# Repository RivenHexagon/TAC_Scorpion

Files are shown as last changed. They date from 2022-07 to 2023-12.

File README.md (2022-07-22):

# TAC_Scorpion
## Mixing Console S1100 Channel Modification

This modification **splits** the TAC Scorpion **S1100** channel **modules** into three **groups** and **modifies** them accordingly:

*   **Group 1**: AML-16-007 ***Mic Input*** Modification<br>
    <http://www.audiomaintenance.com/acatalog/AML-16-007_extended_info.html>
*   **Group 2**: AML-16-004 ***Line Input*** Modification<br>
    <http://www.audiomaintenance.com/acatalog/AML-16-004_extended_info.html>
*   **Group 3**: SK25 ***Descrete Op-Amp*** (DOA) Modification<br>
    <https://www.soundskulptor.com/en/proddetail.php?prod=SK25>

### New Circuit Diagrams
For each modification the **circuit diagram** of the **S1100** module (PBC GL270D) is **redrawn**, reflecting the changes made.

### New Connector Cards
Further more, all **connector cards** are **redesigned**, providing a single layer **PCB layout** for **DIY** manuafcturing. It has slight improvements and allowes for the replacement of old **corroded** connectors with **new** gold plated components.

### This Repo
This repository provides all the **design resources** created for this project. The majority of the modifications are **based** on the reverse engineering of the above linked **Audio Maintenance Limited** products and the **Sound Sculptor** kit.

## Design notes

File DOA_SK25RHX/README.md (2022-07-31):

## Soundskulptor SK 25
<https://www.soundskulptor.com/en/proddetail.php?prod=SK25>
The SK25 Descrete OpAmp module is redesigned with our own layout for DIY process.

### AMEK/TAC Scorpion 2520 Differential Mod

<https://www.pcbway.com/project/share/AMEK_TAC_Scorpion_2520_Differential_Mod___.html>

This is an image
This is an image
This is an image

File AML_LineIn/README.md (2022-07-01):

# AML_TAC_LineIn
Schematic for PCB AML-07-046 (Rev 3)

AML-16-004 - TAC Scorpion "Langley" Line Input Modification Kit (S1000 & S1100)

Langley Designs modification kit for TAC Scorpion (S1000 or S1100) input modules.

Replaces Mic input with Line Level Only input for DAW applications.

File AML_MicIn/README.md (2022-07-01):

# AML_TAC_MicIn
Schematic for PCB AML-07-048 (Rev 4)

AML-16-007 - TAC Scorpion "Langley" Mic Input Upgrade Kit (S1000 & S1100)

Langley Designs mic input upgrade modification kit for TAC Scorpion S1000 & S1100 input modules.

* C01 - 2n2 K100
* C02 - 47u 63 V
* C03 - 47u 63 V
* C04 - 3m3 10 V
* C12 - 3m3 10 V
* C05 - 47u 25 V
* C06 - 47u 25 V
* C07 - 47u 25 V
* C08 - 47u 25 V
* C14 - 47u 25 V
* C20 - 100u 10V

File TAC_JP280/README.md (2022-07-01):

# Total Audio Concepts (TAC) Scorpion Mixing Console Overhaul
## PCB JP280

Redesign of Monitor Connector Card (PCB JP280) in order to populate it with gold
plated Audio Jacks and Molex connectors. The original PCB exceeds the dimensions
of an Eurocard (100 mm x 160 mm) substrate. Luckily it's possible to split it up
into two independet parts, so the layouts can be placed on a copper-plated blank
and etched in a DIY process (see mirrored image of original PCB).

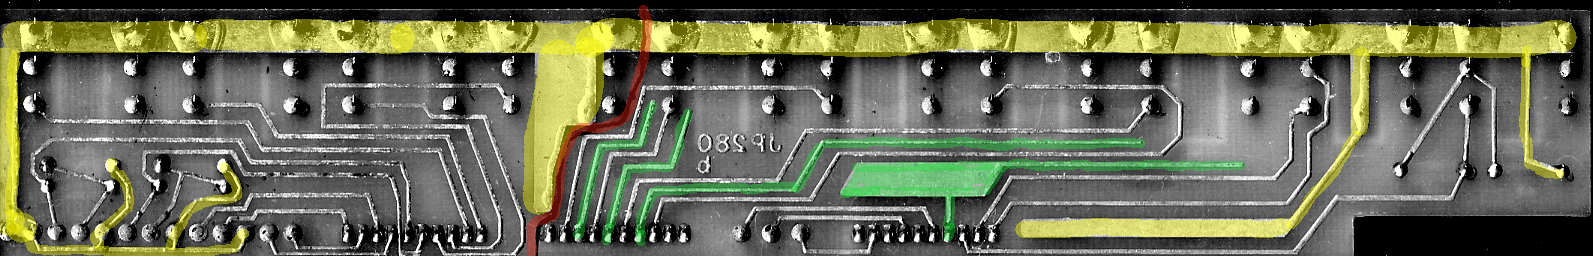
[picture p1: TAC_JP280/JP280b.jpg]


## Made With

I named the new versions JP280C1 & JP280C2 and made them with KiCad 5.1.7. using
a git submodule that handles any special footprints:

https://github.com/RivenHexagon/TAC_KiCad_lib.git

## Further Modifications

The XLR/audio jacks SK1 - SK4 are mounted to the back panel and were then solder
wired to the PCB. The solder connections have now been replaced with 3-pin Molex
connectors.

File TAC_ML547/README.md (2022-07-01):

# Total Audio Concepts (TAC) Scorpion Mixing Console Overhaul
## PCB ML547

Redesign of the Input/Insert Connector Card (PCB ML547) in order to populate it
with gold plated Audio Jacks. The original dimensions are 100 mm x 40 mm. Only
two of them where installed in my TAC scorpion, hence two layouts fit half a
copper plated Eurocard (100 mm x 80 mm) substrate for DIY etching.

## Made With

I named the new version ML547D and made them with KiCad 5.1.7. using a git
submodule that handles any special footprints:

https://github.com/RivenHexagon/TAC_KiCad_lib.git

## Further Modifications

One copper trace of the old layout follows a very narrow path between two pins
of the left and right insert jacks (highlighted in the mirrored PCB image). The
new layout provides this connection with a trace on the top layer. For my single
layer DIY substrate I've used a simple wire.

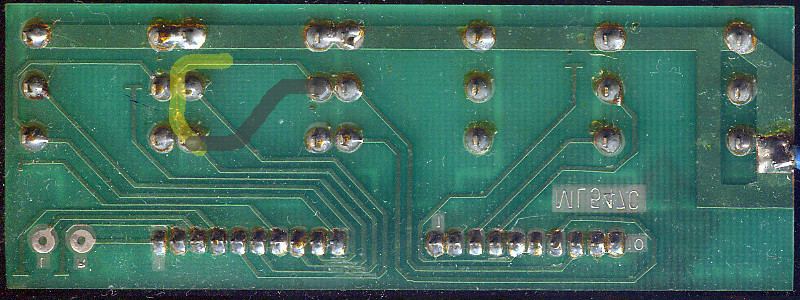
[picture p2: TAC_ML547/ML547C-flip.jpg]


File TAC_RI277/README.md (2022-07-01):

# Total Audio Concepts (TAC) Scorpion Mixing Console Overhaul
## PCB RI277

Redesign of the Input Connector Card (PCB RI277) in order to populate it
with gold plated Audio Jacks. I made 6 of them fit a copper plated Eurocard
(100 mm x 80 mm) substrate for DIY etching.

## Made With

I named the new version RI277D and made them with KiCad 5.1.7. using a git
submodule that handles any special footprints:

https://github.com/RivenHexagon/TAC_KiCad_lib.git

## Further Modifications

The XLR Bus Out connectors were panel mounted and solder wired to the PCB as
well as the Tape Return wiring harness. I've provided two 3-pin Molex connectors
instead.

Mirrored image of the original PCB:

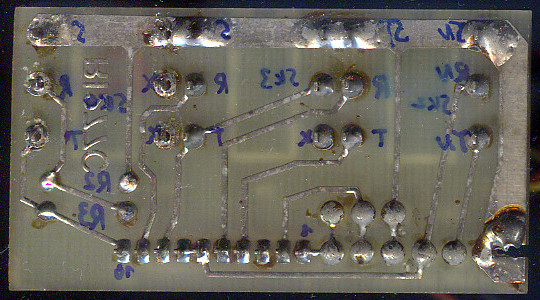
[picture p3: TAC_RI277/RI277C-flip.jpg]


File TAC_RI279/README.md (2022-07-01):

# Total Audio Concepts (TAC) Scorpion Mixing Console Overhaul
## PCB RI279

Redesign of the Bus Connector Card (PCB RI279) in order to populate it
with gold plated Audio Jacks. I made 8 of them fit a copper plated Eurocard
(100 mm x 80 mm) substrate for DIY etching.

## Made With

I named the new version RI279C and made them with KiCad 5.1.7. using a git
submodule that handles any special footprints:

https://github.com/RivenHexagon/TAC_KiCad_lib.git

## Further Modifications

The XLR Bus Out connectors were panel mounted and solder wired to the PCB as
well as the Tape Return wiring harness. I've provided two 3-pin Molex connectors
and a 2-pole pin header (GND and signal) for the wire ging out to the vu-meter.

Mirrored image of the original PCB:

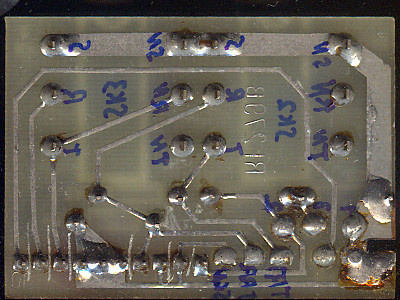
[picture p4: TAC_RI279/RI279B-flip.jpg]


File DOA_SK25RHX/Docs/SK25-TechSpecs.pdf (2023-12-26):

Sound Skulptor - SK 25

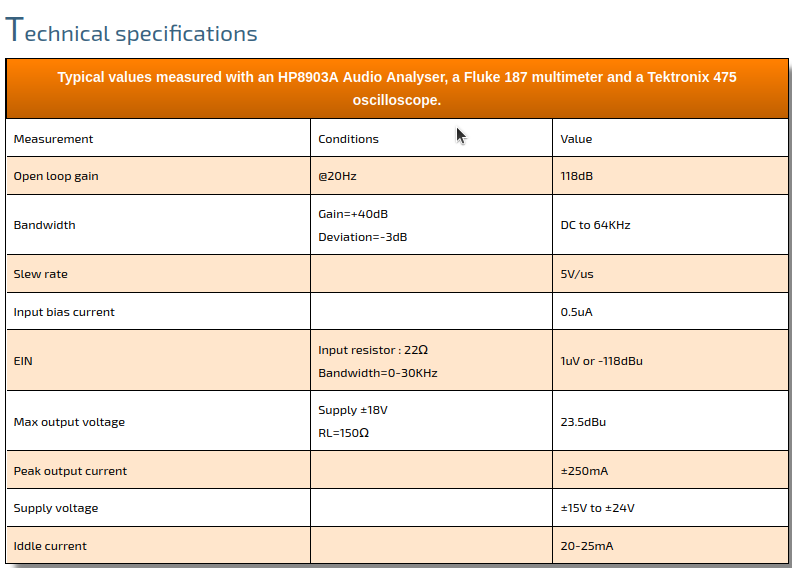
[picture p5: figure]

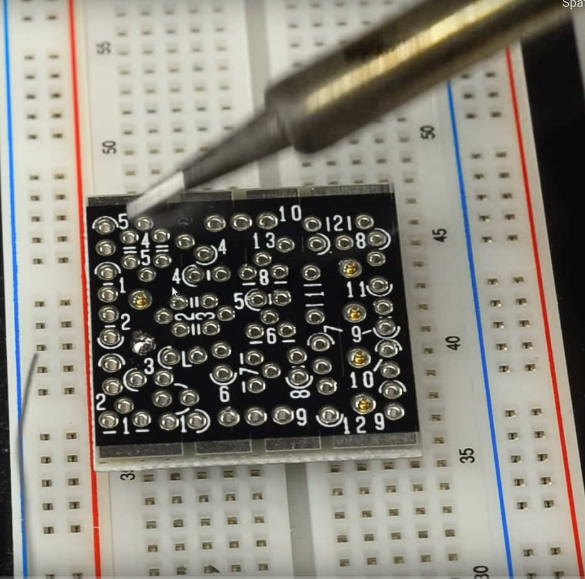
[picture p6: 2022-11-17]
DOA_SK25RHX/Docs/dimensions.jpg

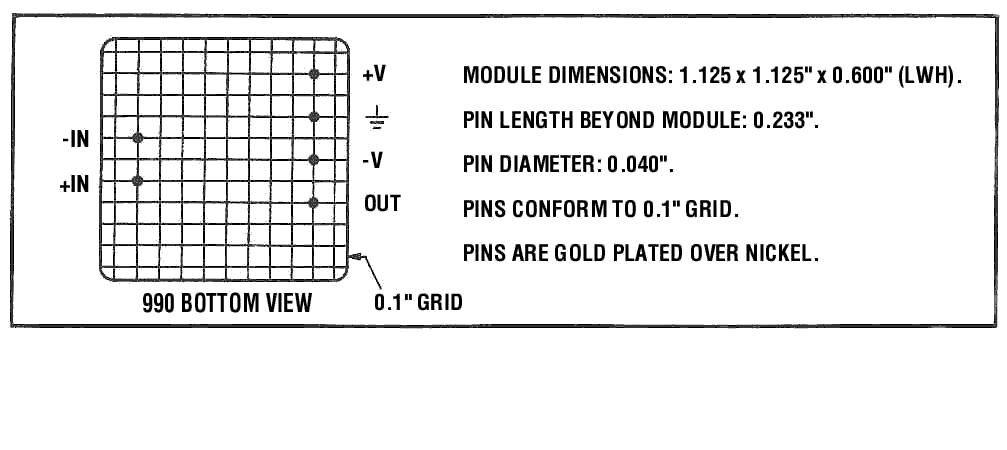
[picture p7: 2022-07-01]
DOA_SK25RHX/Docs/990-2520-footprint.jpeg

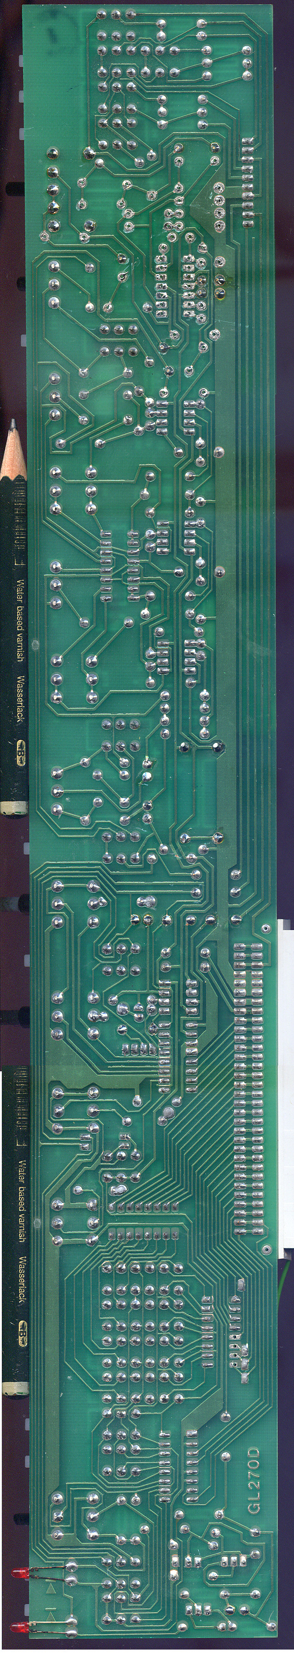
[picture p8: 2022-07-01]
TAC_GL270D/GL270-DOA2520.kicad_pro/PCB_GL270D.jpg

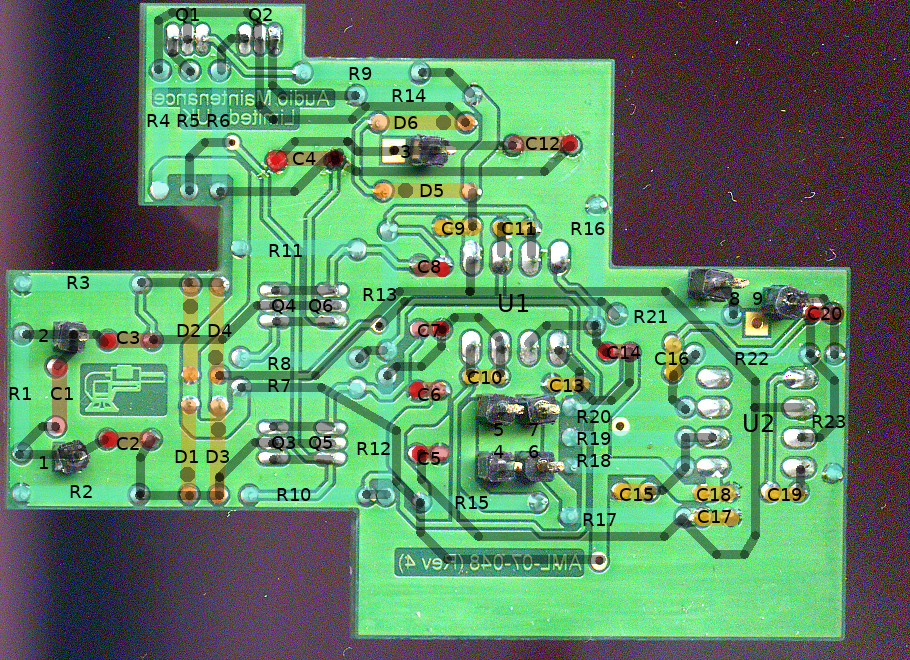
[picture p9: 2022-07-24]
AML_MicIn/AML-MicIn.jpg

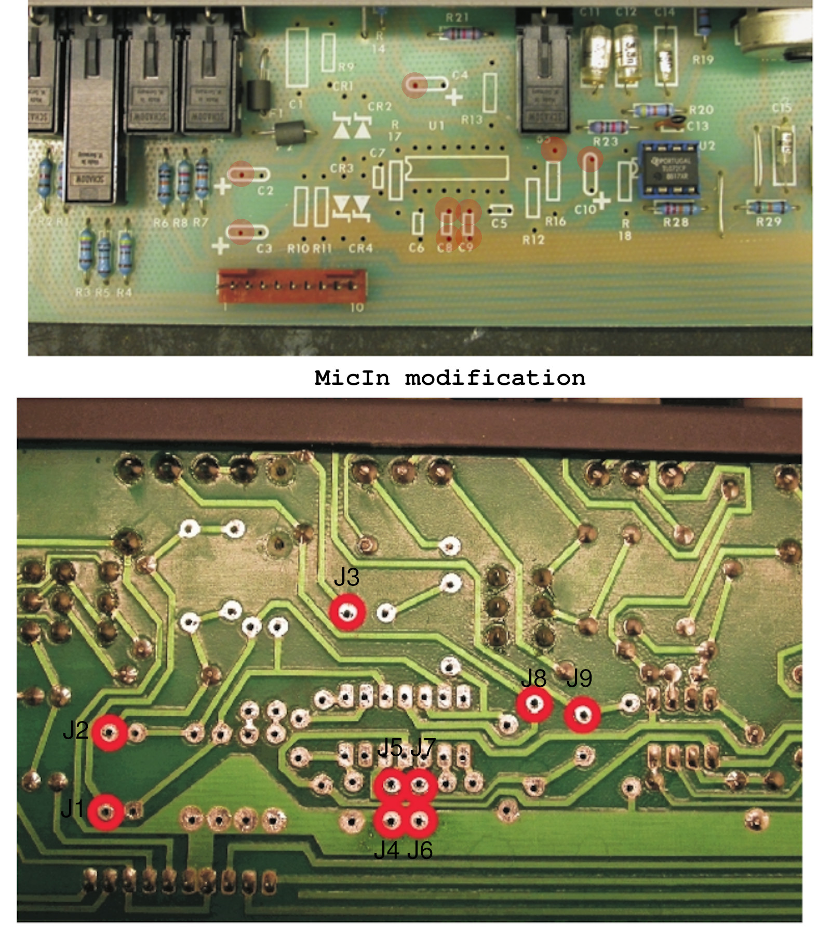
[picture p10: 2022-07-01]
AML_MicIn/MicIn-mod.jpg

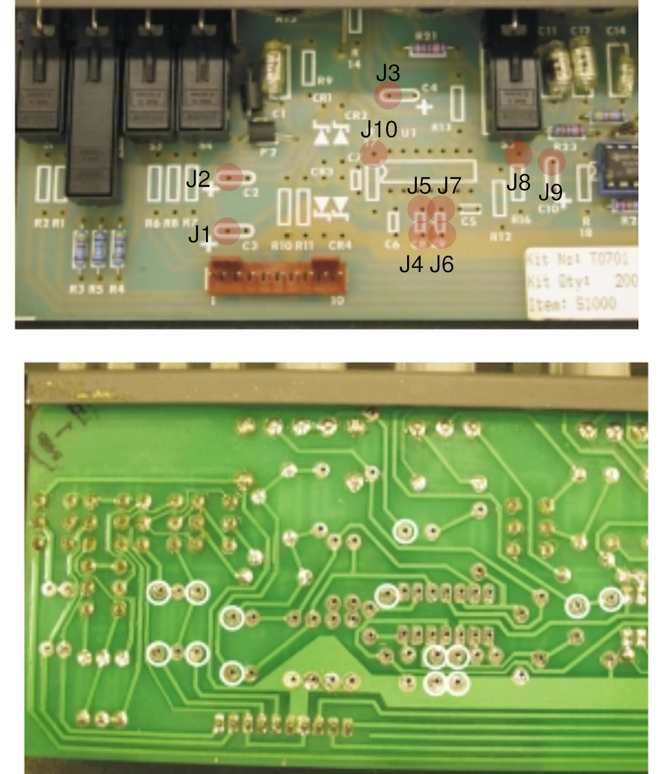
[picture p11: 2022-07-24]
AML_LineIn/LineIn-mod.jpg

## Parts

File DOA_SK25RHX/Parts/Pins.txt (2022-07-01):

 (6) Mill-Max #3103200210000080 @ $0.20 each
Contact Finish: 20μ" Gold Over Nickel
Flange Diameter: 0.070" (1.77mm)
Plated Thru Hole Diameter: 0.043" (1.09mm)
Pin Diameter: 0.040" (1.02mm)
Length: 0.402" (10.21mm)

https://www.digikey.de/products/de?keywords=3103-2-00-21-00-00-08-0
https://capi-gear.com/catalog/product_info.php?products_id=215

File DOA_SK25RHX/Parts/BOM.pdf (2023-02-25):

Sheet1

Reference(s) Value | LibPart
C1 | 100pF | Device:C
C2 | 220pF | Device:C
D1 | 1N914 | Device:D
D2 | 1N914 | Device:D
D3 | red | Device:LED
D4 | Z5V1 | Device:D_Zener
D5 | 1N914 | Device:D
D6 | 1N914 | Device:D
D7 | 1N914 | Device:D
D8 | 1N914 | Device:D
D9 | 1N914 | Device:D
J1 | Input- | Connector:Conn_01x01_Male
J2 | Input+ | Connector:Conn_01x01_Male
J3 | V+ | Connector:Conn_01x01_Male
J4 | Output | Connector:Conn_01x01_Male
J5 | V- | Connector:Conn_01x01_Male
J6 | GND | Connector:Conn_01x01_Male
L1 | 22µH | Device:L
Q1 | BC560C | Device:Q_PNP_CBE
Q2 | KSA992 | Device:Q_PNP_ECB
Q3 | KSA992 | Device:Q_PNP_ECB
Q4 | BC550C | Device:Q_NPN_CBE
Q5 | BC550C | Device:Q_NPN_CBE
Q6 | BC550C | Device:Q_NPN_CBE
Q7 | BC556C | Device:Q_PNP_CBE
Q8 | BC546C | Device:Q_NPN_CBE
Q9 | BD139 | Device:Q_NPN_ECBC
Q10 | BD140 | Device:Q_PNP_ECBC
R1 | 2k2 | Device:R
R2 | 100R | Device:R
R3 | 100R | Device:R
R4 | 2k2 | Device:R
R5 | 2k2 | Device:R
R6 | 22k | Device:R
R7 | 39R | Device:R
R8 | 2k2 | Device:R
R9 | 220R | Device:R
R10 | 22R | Device:R
R11 | 100R | Device:R
R12 | 5R6 | Device:R
R13 | 5R6 | Device:R

Sheet1

Footprint

Capacitor_THT:C_Disc_D5.0mm_W2.5mm_P2.50mm

Capacitor_THT:C_Disc_D5.0mm_W2.5mm_P2.50mm

Diode_THT:D_DO-35_SOD27_P2.54mm_Vertical_KathodeUp

Diode_THT:D_DO-35_SOD27_P2.54mm_Vertical_KathodeUp

LED_THT:LED_D3.0mm

Diode_THT:D_DO-35_SOD27_P2.54mm_Vertical_AnodeUp

Diode_THT:D_DO-35_SOD27_P10.16mm_Horizontal

Diode_THT:D_DO-35_SOD27_P10.16mm_Horizontal

Diode_THT:D_DO-35_SOD27_P2.54mm_Vertical_KathodeUp

Diode_THT:D_DO-35_SOD27_P2.54mm_Vertical_KathodeUp

Diode_THT:D_DO-35_SOD27_P2.54mm_Vertical_KathodeUp

Connector_Pin:Pin_D1.1mm_L8.5mm_W2.5mm_FlatFork

Connector_Pin:Pin_D1.1mm_L8.5mm_W2.5mm_FlatFork

Connector_Pin:Pin_D1.1mm_L8.5mm_W2.5mm_FlatFork

Connector_Pin:Pin_D1.1mm_L8.5mm_W2.5mm_FlatFork

Connector_Pin:Pin_D1.1mm_L8.5mm_W2.5mm_FlatFork

Connector_Pin:Pin_D1.1mm_L8.5mm_W2.5mm_FlatFork

Inductor_THT:L_Axial_L6.6mm_D2.7mm_P2.54mm_Vertical_Vishay_IM-2

TAC:TO-92

TAC:TO-92

TAC:TO-92

TAC:TO-92

TAC:TO-92

TAC:TO-92

TAC:TO-92

TAC:TO-92

TAC:to225_std

TAC:to225_std

Resistor_THT:R_Axial_DIN0207_L6.3mm_D2.5mm_P2.54mm_Vertical

Resistor_THT:R_Axial_DIN0207_L6.3mm_D2.5mm_P2.54mm_Vertical

Resistor_THT:R_Axial_DIN0207_L6.3mm_D2.5mm_P2.54mm_Vertical

Resistor_THT:R_Axial_DIN0207_L6.3mm_D2.5mm_P2.54mm_Vertical

Resistor_THT:R_Axial_DIN0207_L6.3mm_D2.5mm_P2.54mm_Vertical

Resistor_THT:R_Axial_DIN0207_L6.3mm_D2.5mm_P2.54mm_Vertical

Resistor_THT:R_Axial_DIN0207_L6.3mm_D2.5mm_P2.54mm_Vertical

Resistor_THT:R_Axial_DIN0207_L6.3mm_D2.5mm_P2.54mm_Vertical

Resistor_THT:R_Axial_DIN0207_L6.3mm_D2.5mm_P2.54mm_Vertical

Resistor_THT:R_Axial_DIN0207_L6.3mm_D2.5mm_P2.54mm_Vertical

Resistor_THT:R_Axial_DIN0207_L6.3mm_D2.5mm_P2.54mm_Vertical

Resistor_THT:R_Axial_DIN0207_L6.3mm_D2.5mm_P2.54mm_Vertical

Resistor_THT:R_Axial_DIN0207_L6.3mm_D2.5mm_P2.54mm_Vertical

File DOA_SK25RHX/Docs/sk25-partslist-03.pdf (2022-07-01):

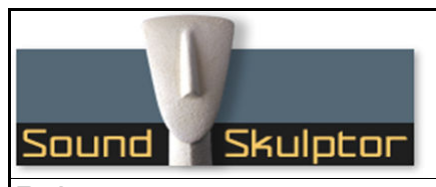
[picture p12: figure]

Reference | Value | Qty | Description | Marking
R12, R13 | 5R6 | 2 | Resistor 1%, 1/4W | GRN-BLU-BLK-SLV
R10 | 22R | 1 | Resistor 1%, 1/4W | RED-RED-BLK-GLD-BRN
R7 | 39R | 1 | Resistor 1%, 1/4W | ORG-WHT-BLK-GLD-BRN
R2, R3, R11 | 100R | 3 | Resistor 1%, 1/4W | BRN-BLK-BLK-BLK-BRN
R9 | 220R | 1 | Resistor 1%, 1/4W | RED-RED-BLK-BLK-BRN
R1, R4, R5, R8 | 2K2 | 4 | Resistor 1%, 1/4W | RED-RED-BLK-BRN-BRN
R6 | 22K | 1 | Resistor 1%, 1/4W | RED-RED-BLK-RED-BRN
L1 | 22uH | 1 | Inductor | RED-RED-BLK-SLV
C1 | 100pF | 1 | Capacitor ceramic | 101
C2 | 220pF | 1 | Capacitor ceramic | 221
D1, D2, D5, D6, D7, D8, D9 | 1N914 | 7 | Signal diode | 914 or 4148
D3 | Red | 1 | Red LED
D4 | 5.1V | 1 | Zener diode | BZX55C 5V1
Q1 | BC560C | 1 | PNP small signal transistor | BC560C
Q2, Q3 | KSA992 | 2 | PNP small signal transistor | A992
Q4, Q5, Q6 | BC550C | 3 | NPN small signal transistor | BC550C
Q7 | BC556C | 1 | PNP small signal transistor | BC556C
Q8 | BC546C | 1 | NPN small signal transistor | BC546C
Q9 | BD139 | 1 | NPN power transistor | BD139
Q10 | BD140 | 1 | PNP power transistor | BD140
| | 6 | connecting pin (golden)
PCB | | 1 | PCB
Power transistor assembly | M3x12 | 2 | Screw pan head
Power transistor assembly | M3x20 | 1 | Spacer

Last modified : 10/09/2016

### SK25 Parts list (1)

All the components in this list are included in the kit

(1) Data can be changed without notice
Page 1/1 | Copyright ©2007-today SoundSkulptor

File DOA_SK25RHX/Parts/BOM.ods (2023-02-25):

Reference(s) | Value | LibPart | Footprint
C1 | 100pF | Device:C | Capacitor_THT:C_Disc_D5.0mm_W2.5mm_P2.50mm
C2 | 220pF | Device:C | Capacitor_THT:C_Disc_D5.0mm_W2.5mm_P2.50mm
D1 | 1N914 | Device:D | Diode_THT:D_DO-35_SOD27_P2.54mm_Vertical_KathodeUp
D2 | 1N914 | Device:D | Diode_THT:D_DO-35_SOD27_P2.54mm_Vertical_KathodeUp
D3 | red | Device:LED | LED_THT:LED_D3.0mm
D4 | Z5V1 | Device:D_Zener | Diode_THT:D_DO-35_SOD27_P2.54mm_Vertical_AnodeUp
D5 | 1N914 | Device:D | Diode_THT:D_DO-35_SOD27_P10.16mm_Horizontal
D6 | 1N914 | Device:D | Diode_THT:D_DO-35_SOD27_P10.16mm_Horizontal
D7 | 1N914 | Device:D | Diode_THT:D_DO-35_SOD27_P2.54mm_Vertical_KathodeUp
D8 | 1N914 | Device:D | Diode_THT:D_DO-35_SOD27_P2.54mm_Vertical_KathodeUp
D9 | 1N914 | Device:D | Diode_THT:D_DO-35_SOD27_P2.54mm_Vertical_KathodeUp
J1 | Input- | Connector:Conn_01x01_Male | Connector_Pin:Pin_D1.1mm_L8.5mm_W2.5mm_FlatFork
J2 | Input+ | Connector:Conn_01x01_Male | Connector_Pin:Pin_D1.1mm_L8.5mm_W2.5mm_FlatFork
J3 | V+ | Connector:Conn_01x01_Male | Connector_Pin:Pin_D1.1mm_L8.5mm_W2.5mm_FlatFork
J4 | Output | Connector:Conn_01x01_Male | Connector_Pin:Pin_D1.1mm_L8.5mm_W2.5mm_FlatFork
J5 | V- | Connector:Conn_01x01_Male | Connector_Pin:Pin_D1.1mm_L8.5mm_W2.5mm_FlatFork
J6 | GND | Connector:Conn_01x01_Male | Connector_Pin:Pin_D1.1mm_L8.5mm_W2.5mm_FlatFork
L1 | 22µH | Device:L | Inductor_THT:L_Axial_L6.6mm_D2.7mm_P2.54mm_Vertical_Vishay_IM-2
Q1 | BC560C | Device:Q_PNP_CBE | TAC:TO-92
Q2 | KSA992 | Device:Q_PNP_ECB | TAC:TO-92
Q3 | KSA992 | Device:Q_PNP_ECB | TAC:TO-92
Q4 | BC550C | Device:Q_NPN_CBE | TAC:TO-92
Q5 | BC550C | Device:Q_NPN_CBE | TAC:TO-92
Q6 | BC550C | Device:Q_NPN_CBE | TAC:TO-92
Q7 | BC556C | Device:Q_PNP_CBE | TAC:TO-92
Q8 | BC546C | Device:Q_NPN_CBE | TAC:TO-92
Q9 | BD139 | Device:Q_NPN_ECBC | TAC:to225_std
Q10 | BD140 | Device:Q_PNP_ECBC | TAC:to225_std
R1 | 2k2 | Device:R | Resistor_THT:R_Axial_DIN0207_L6.3mm_D2.5mm_P2.54mm_Vertical
R2 | 100R | Device:R | Resistor_THT:R_Axial_DIN0207_L6.3mm_D2.5mm_P2.54mm_Vertical
R3 | 100R | Device:R | Resistor_THT:R_Axial_DIN0207_L6.3mm_D2.5mm_P2.54mm_Vertical
R4 | 2k2 | Device:R | Resistor_THT:R_Axial_DIN0207_L6.3mm_D2.5mm_P2.54mm_Vertical
R5 | 2k2 | Device:R | Resistor_THT:R_Axial_DIN0207_L6.3mm_D2.5mm_P2.54mm_Vertical
R6 | 22k | Device:R | Resistor_THT:R_Axial_DIN0207_L6.3mm_D2.5mm_P2.54mm_Vertical
R7 | 39R | Device:R | Resistor_THT:R_Axial_DIN0207_L6.3mm_D2.5mm_P2.54mm_Vertical
R8 | 2k2 | Device:R | Resistor_THT:R_Axial_DIN0207_L6.3mm_D2.5mm_P2.54mm_Vertical
R9 | 220R | Device:R | Resistor_THT:R_Axial_DIN0207_L6.3mm_D2.5mm_P2.54mm_Vertical
R10 | 22R | Device:R | Resistor_THT:R_Axial_DIN0207_L6.3mm_D2.5mm_P2.54mm_Vertical
R11 | 100R | Device:R | Resistor_THT:R_Axial_DIN0207_L6.3mm_D2.5mm_P2.54mm_Vertical
R12 | 5R6 | Device:R | Resistor_THT:R_Axial_DIN0207_L6.3mm_D2.5mm_P2.54mm_Vertical
R13 | 5R6 | Device:R | Resistor_THT:R_Axial_DIN0207_L6.3mm_D2.5mm_P2.54mm_Vertical

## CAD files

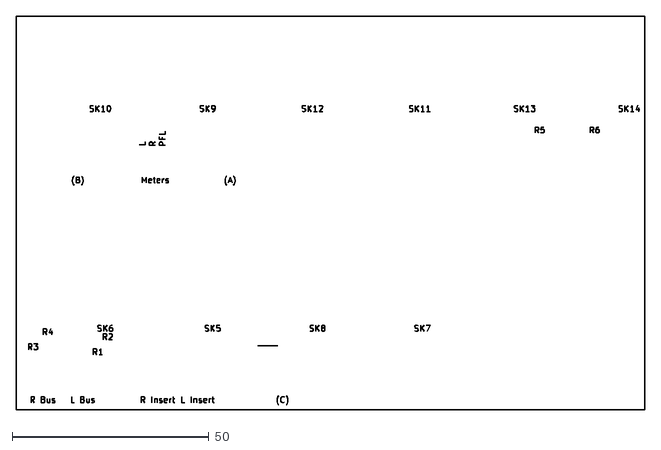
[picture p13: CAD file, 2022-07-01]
TAC_JP280/JP280C-Cmts_User.dxf
160.0 x 100.0

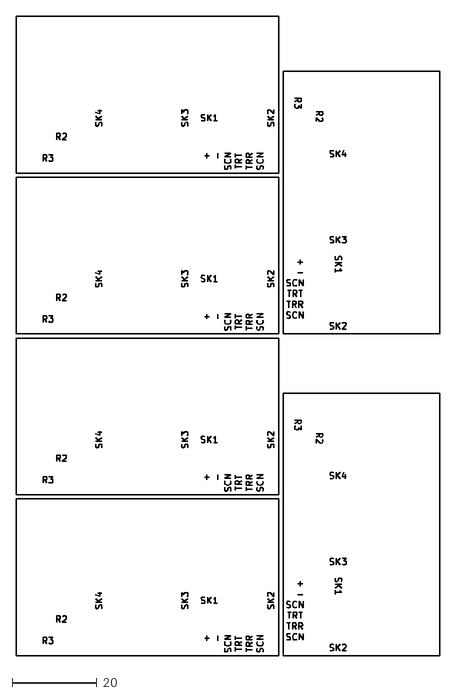
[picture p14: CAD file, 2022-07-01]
TAC_RI277/RI277D-Cmts_User.dxf
100.0 x 151.0

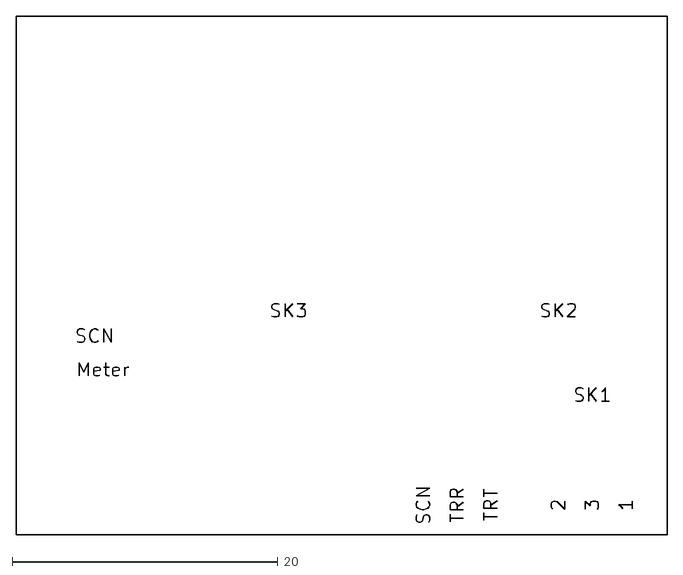
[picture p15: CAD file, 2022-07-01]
TAC_RI279/RI279C-Cmts_User.dxf
49.0 x 39.0

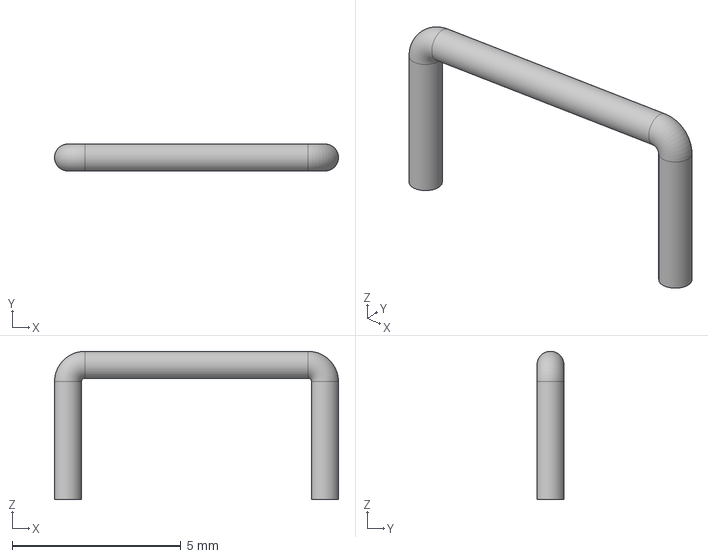
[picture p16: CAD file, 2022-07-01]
TAC_KiCad_lib/local-3dmodels/Wire_Bridge_P7.62mm.step
8.42 x 0.8 x 4.40 mm

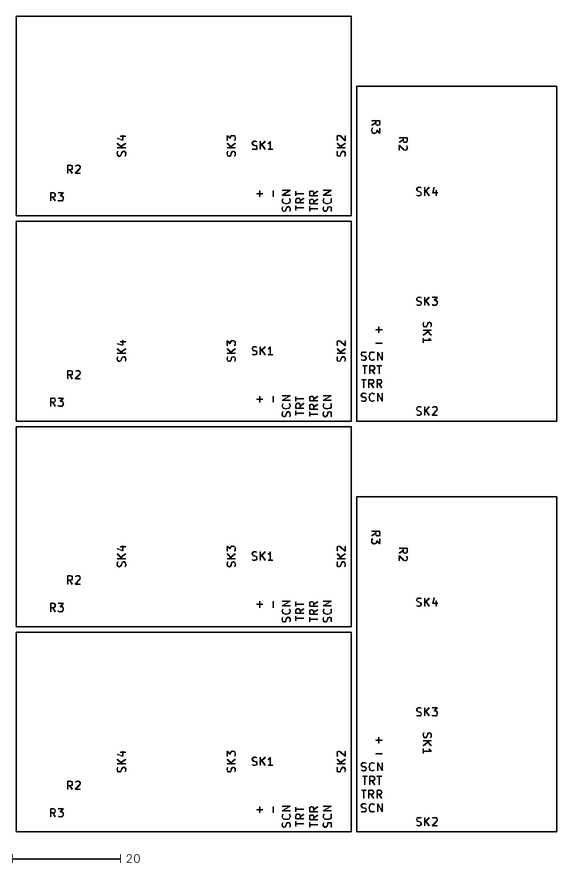
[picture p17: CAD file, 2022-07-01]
TAC_RI277/RI277D-Cmts_User-R27.dxf
100.0 x 151.0

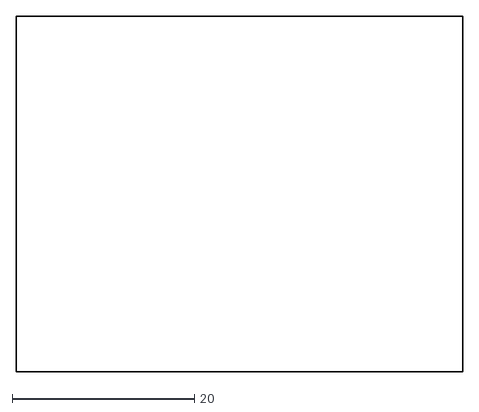
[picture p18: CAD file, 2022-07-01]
TAC_RI279/RI279C-Edge_Cuts.dxf
49.0 x 39.0

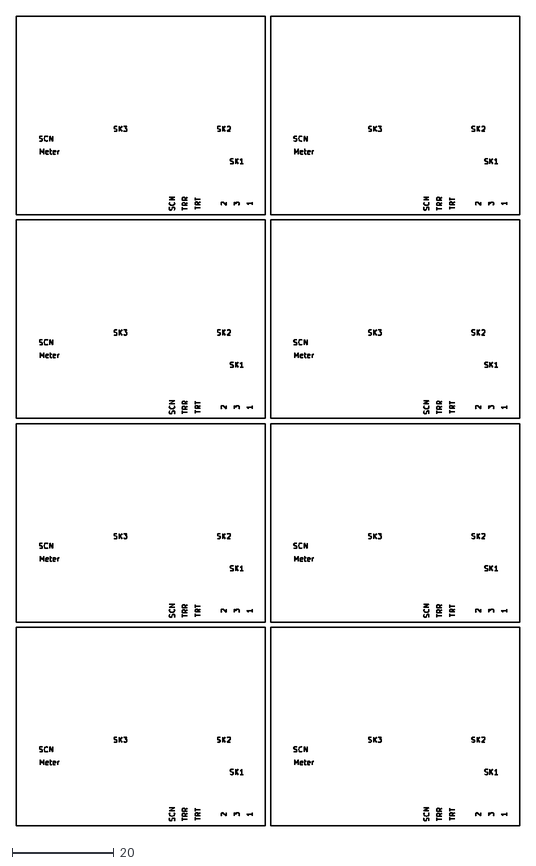
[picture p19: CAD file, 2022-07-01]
TAC_RI279/RI279C-Cmts_User-R27.dxf
99.0 x 159.0

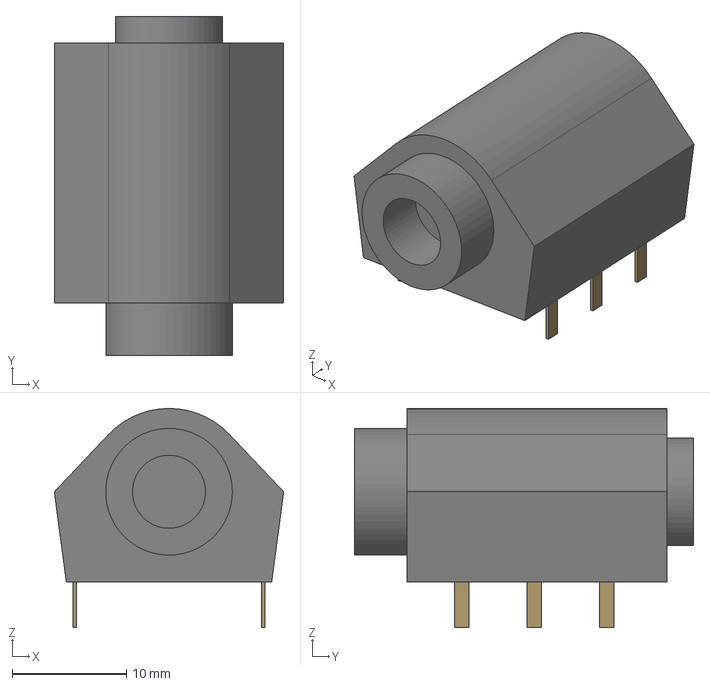
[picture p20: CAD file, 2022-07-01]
TAC_KiCad_lib/local-3dmodels/CL13345.step
20.1 x 29.7 x 19.2 mm

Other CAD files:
TAC_KiCad_lib/local-3dmodels/CL13345.FCStd
TAC_KiCad_lib/local-3dmodels/WireBridge_P7.62mm.FCStd

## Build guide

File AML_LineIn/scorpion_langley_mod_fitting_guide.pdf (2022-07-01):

# Scorpion Line Input Modification Fitting Instructions - Issue 1.1

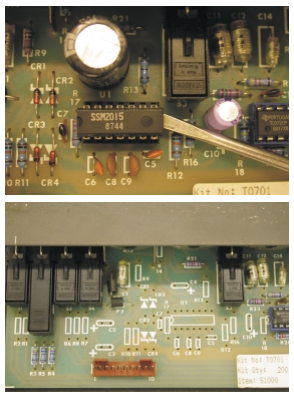
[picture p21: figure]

Carefully remove U1 (SSM2015) from its socket - Note that it is a static sensitive device and should be handled and stored appropriately.

Carefully remove the following components

Resistors; R1, R2, R6, R7, R8, R9, R10, R11, R12, R13, R14, R16, R17, R18

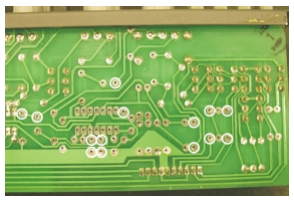
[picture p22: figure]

Capacitors; C2, C3, C4, C5, C6, C7, C8, C9, C10

Diodes; CR1, CR2, CR3, CR4

Ensure that the holes highlighted are free from solder

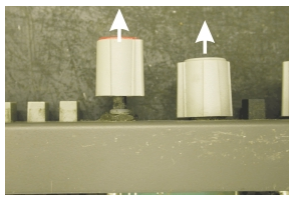
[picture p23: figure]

Carefully remove the knobs by pulling them off

{They should come off quite easily - If they do not pull off easily then remove the coloured knob cap and check to see if they are “collet” knobs with a nut inside the knob}

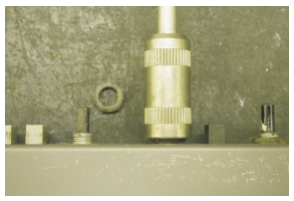
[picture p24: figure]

Remove the pot nuts with a 10mm nut runner

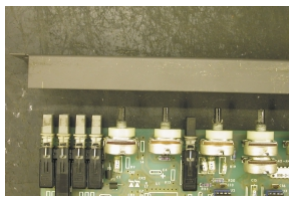
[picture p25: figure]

You should now be able to pull off the faceplate

{Be careful not to lose the white plastic washers on the pots.... Some of them may be stuck to the back of the faceplate}

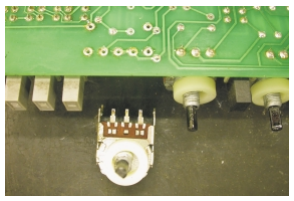
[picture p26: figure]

Remove the mic gain pot and desolder the holes.

{Be careful not to damage the circuit board..... If necessary destroy the pot as they only cost a few pence.... The circuit board is irreplaceable...}

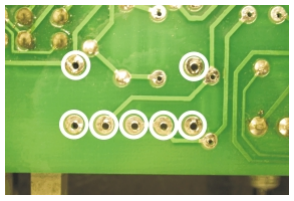
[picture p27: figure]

Ensure that the holes highlighted are free from solder

Using a sharp craft knife, cut the track which connects the 2 pins of the pot (pot wiper and pot bottom) as indicated.

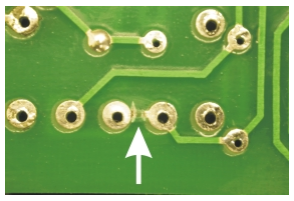
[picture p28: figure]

{Check with an Ohmmeter to ensure that the cut is sucessful}

Fit the new replacement pot.

Re-fit the faceplate and knobs

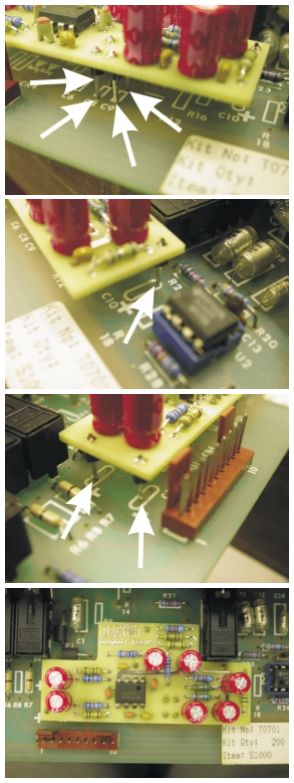
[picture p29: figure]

Fit the line input module into the PCB- the pins should line up with the positions indicated - press all the way down onto main PCB

{If fitting to a Scorpion II input module the 2 of the pins will need to be moved into the “alternative locations”}

Solder the module in place and cut off the excess pins

It should look like this.....

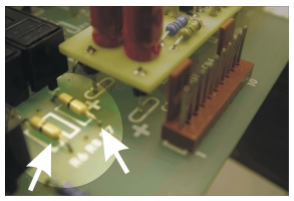
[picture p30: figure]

Fit the zero Ohm links in the R6 and R7 positions

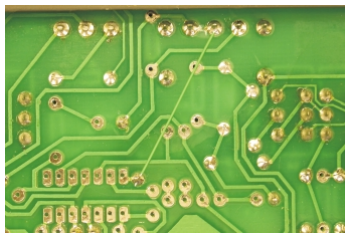
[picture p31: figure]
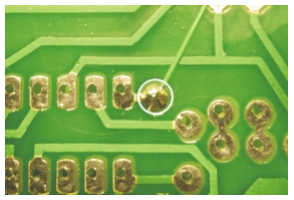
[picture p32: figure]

Fit a wire link between the wiper pin of the pot and the pad attached to U1 pin 14 (SSM2015)...

{Keep the wire as short as possible}

Change of PAD from -20dB to -10dB

Carefully remove the following components;

Resistors; R3, R4, R5 Capacitor; C1

Replace R3 and R4 with the 4k7 resistors provided

Replace R5 with the 3k9 resistor provided

Replace C1 with the 220pF capacitor provided

This change is highly recommended as it also corrects the pad impedance for use with a line input signal.

Replacement of Electrolytic Capacitors

Carefully remove the following components;

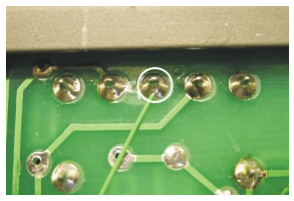
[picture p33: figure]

CapacitorS; C22, C24, C25, C26, C27, C29, C30, C31 & C32

Replace C22, C24, C25, C26, C27 & C29 with the 100uF / 25v capacitors provided

Replace C30 with the 2u2F / 63v capacitor provided

Replace C31 & C32 with the 220uF / 25v axial capacitors provided

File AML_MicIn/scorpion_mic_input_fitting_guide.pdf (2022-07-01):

# Scorpion Mic Input Modification Fitting Instructions - Issue 1.0

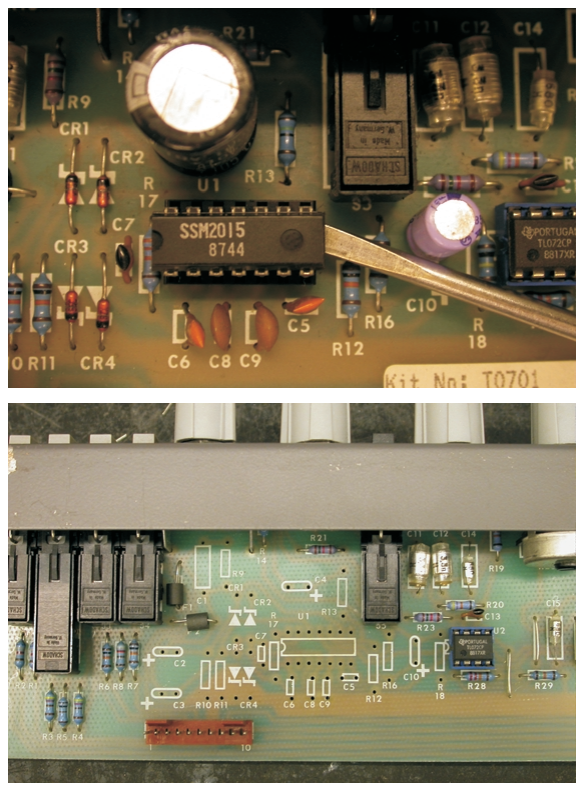
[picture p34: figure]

Carefully remove U1 (SSM2015) from its socket - Note that it is a static sensitive device and should be handled and stored appropriately.

Carefully remove the following components

Resistors; R9, R10, R11, R12, R13, R14, R16, R17, R18

Capacitors; C1, C2, C3, C4, C5, C6, C7, C8, C9, C10

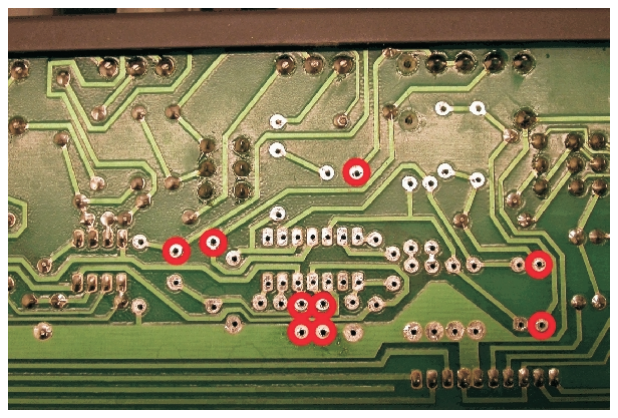
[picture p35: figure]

Diodes; CR1, CR2, CR3, CR4

Socket: U1

Ensure that the holes highlighted are free from solder

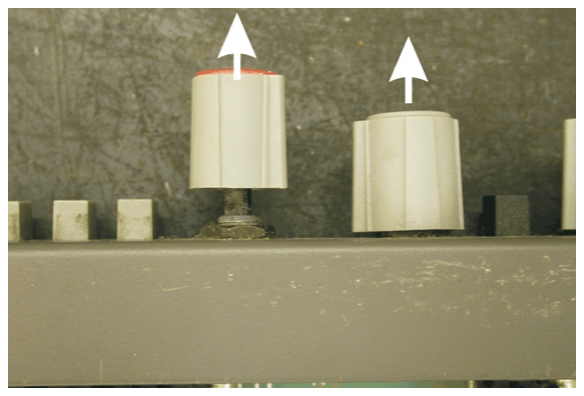
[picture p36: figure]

Carefully remove the knobs by pulling them off

{They should come off quite easily - If they do not pull off easily then remove the coloured knob cap and check to see if they are “collet” knobs with a nut inside the knob}

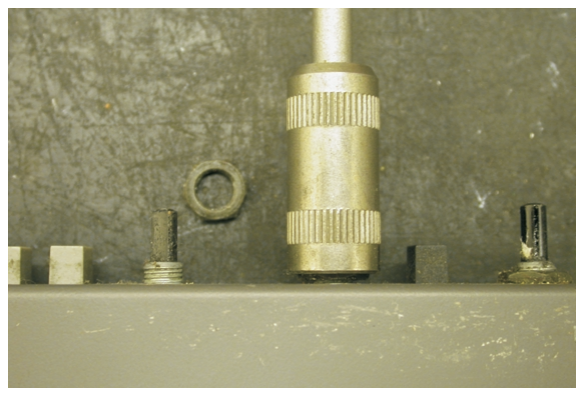
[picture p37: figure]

Remove the pot nuts with a 10mm nut runner

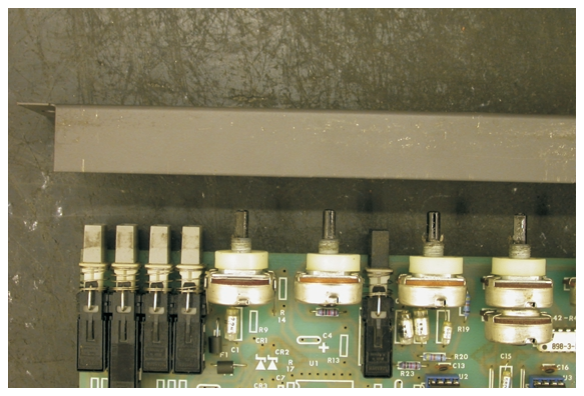
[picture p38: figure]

You should now be able to pull off the faceplate

{Be careful not to lose the white plastic washers on the pots.... Some of them may be stuck to the back of the faceplate}

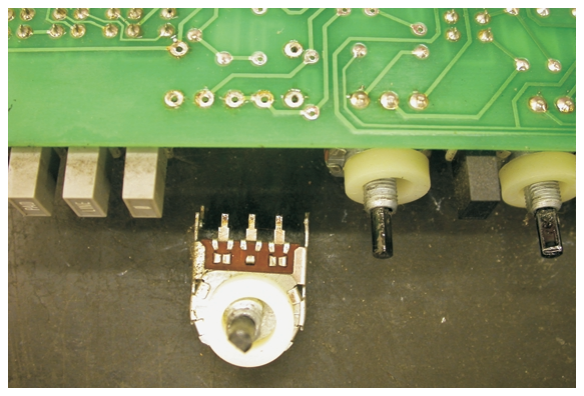
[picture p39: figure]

Remove the mic gain pot and desolder the holes.

{Be careful not to damage the circuit board..... If necessary destroy the pot as they only cost a few pence.... The circuit board is irreplaceable...}

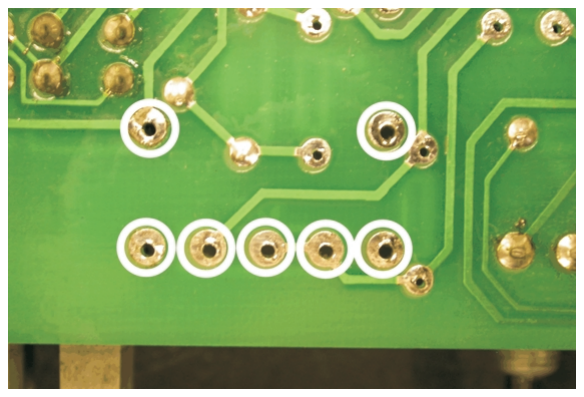
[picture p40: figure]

Ensure that the holes highlighted are free from solder

Fit the new replacement pot.

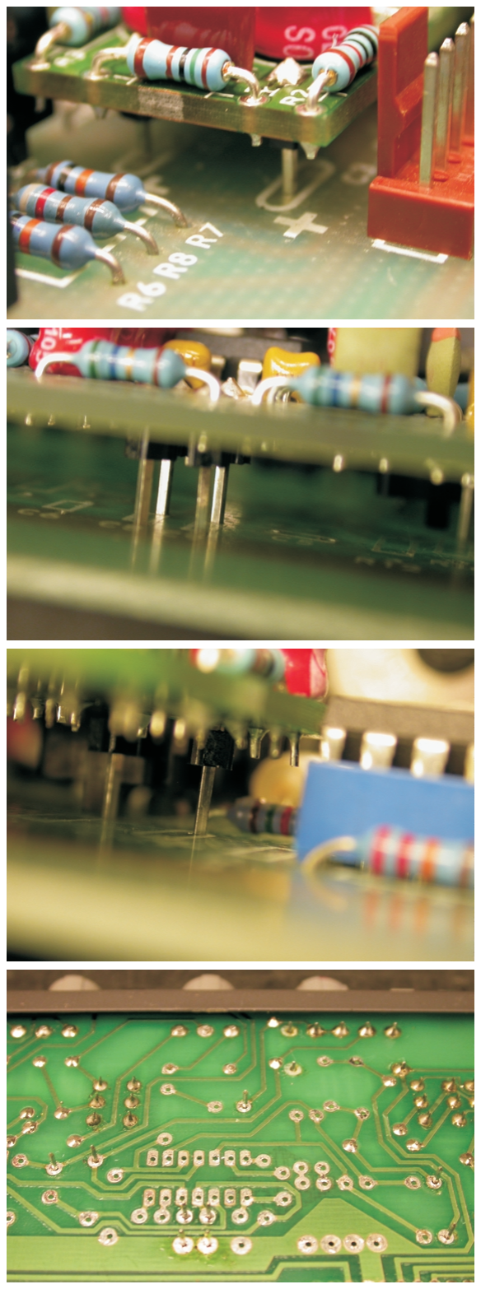
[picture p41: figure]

Re-fit the faceplate and knobs

Fit the mic input module into the PCB- the pins should line up with the positions indicated - press all the way down onto main PCB

Solder the module in place and cut off the excess pins

It should look like this.....

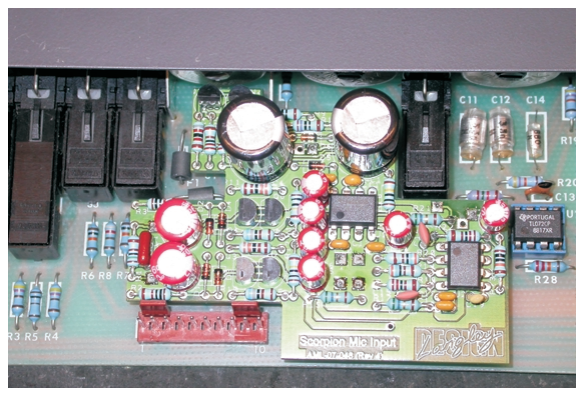
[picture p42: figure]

Replacement of Electrolytic Capacitors

Carefully remove the following components;

CapacitorS; C22, C24, C25, C26, C27, C29, C30, C31 & C32

Replace C22, C24, C25, C26, C27 & C29 with the 100uF / 25v capacitors provided

Replace C30 with the 2u2F / 63v capacitor provided

Replace C31 & C32 with the 220uF / 25v axial capacitors provided

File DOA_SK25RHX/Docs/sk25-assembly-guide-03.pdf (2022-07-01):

www.soundskulptor.com

Document revision 1.1 – Last modification : 10/08/17

SK25 Assembly guide

Safety warning

The kits are main powered and use potentially lethal voltages. Under no circumstance should someone undertake the realisation of a kit unless he has full knowledge about safely handling main powered devices.

Please read the “DIY guide” before beginning.
Print or open the following documents :
- SK25 Schematics
- SK25 Components layout
- SK25 Parts list

Follow this guide from item number 1 till the end, in this order. The assembly order is based on components height, from low to high profile, in order to ease the soldering process : The component you are soldering is always taller than the previously assembled ones and it is pressing nicely against the work area foam.

SK25 Assembly guide
1. Soldering
All the PCB holes are metallized. It means the connection between the top and bottom pads is already done. The parts must be soldered only from the bottom side (unless differently stated).
Use only small diameter solder, 0.5 or 0.7 mm, 1mm maximum. Use the minimum possible amount of solder. Bad joints are almost always caused by too much solder.
Here are two excellent introduction to soldering videos: http://www.eevblog.com/2011/06/19/eevblog-180-soldering-tutorial-part-1-tools/http://www.eevblog.com/2011/07/02/eevblog-183-soldering-tutorial-part-2/
2. PCB split

Split the PCB into 3 parts along the lines shown by the red arrows.

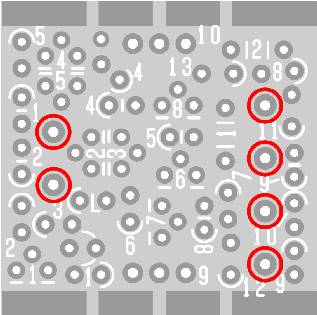
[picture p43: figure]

3. Pins

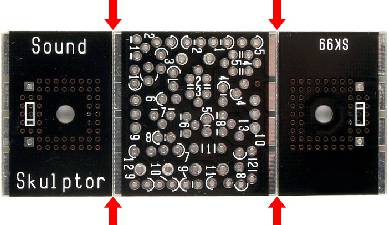
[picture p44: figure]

Insert and solder the 6 golden pins. The pins are inserted from below the PCB.
The best solution to keep the pins perfectly perpendicular is to use the final host PCB (like the MP512, MP599) as a guide: Insert the 6 pins into the 1mm sockets of the receiving PCB, position the DOA PCB over the pins and solder.
It is a good idea to protect the golden pins with some wire insulating sleeve before doing other component soldering.

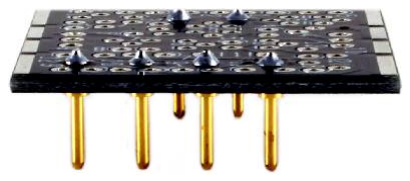
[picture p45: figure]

Copyright ©2014 to Today SoundSkulptor

SK25 Assembly guide
4. Diodes D5 & D6
Add D5 and D6 on the 2 heatsink PCB's.
When soldering, be careful not putting any solder on the power transistor plane.
Warning: Make sure to respect the direction of the diodes which is marked by a ring on the component and a double line on the PCB marking.

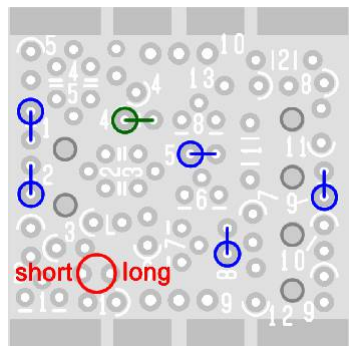
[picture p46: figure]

5. Other diodes
These diodes are mounted
vertically, cathode (black ring) up.
Add D1, D2, D7, D8, D9:
1N4148, blue on the picture.
Add D4: zener 5.1V, green on
the picture.

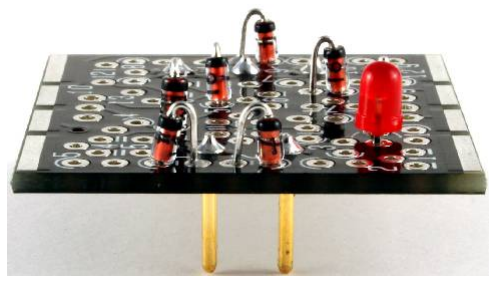
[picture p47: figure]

Warning : Make sure to respect the direction of the diodes. D7, D8, D9 are mis-labeled on the PCB, follow the layout document.
6. LED
Add the red LED D3, red on the picture.
Warning : Make sure to respect the long lead/short lead direction of the diode.

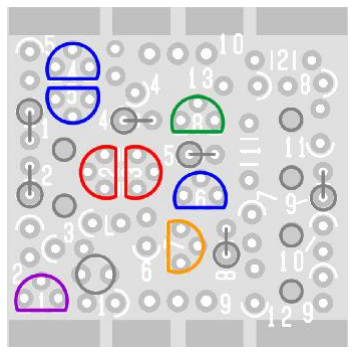
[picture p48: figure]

7. Transistors
Add Q1: BC560C (purple)
Add Q2, Q3: KSA992 (red)
Add Q4, Q5, Q6: BC550C (blue)
Add Q7: BC556C (orange)
Add Q8: BC546C (green)
Press firmly the transistors against the PCB in order to keep the profile low.

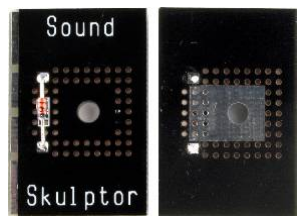
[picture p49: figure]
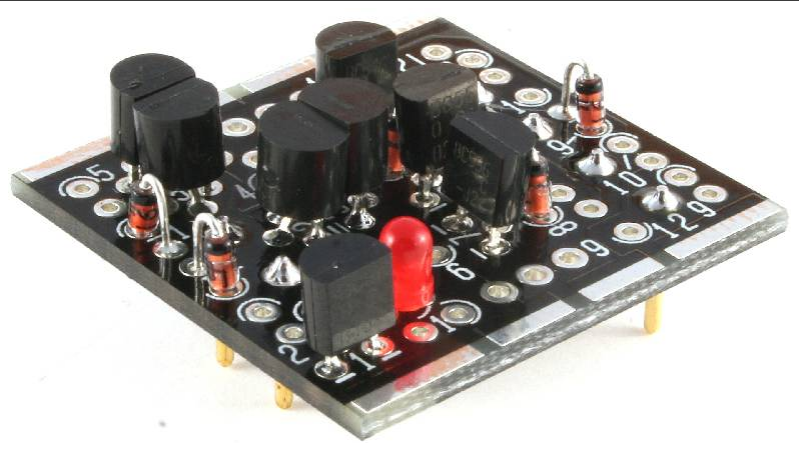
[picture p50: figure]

SK25 Assembly guide
8. Inductor
Add L1 (red).
Bend sharply one of the leads against the body of L1 for a vertical insertion.

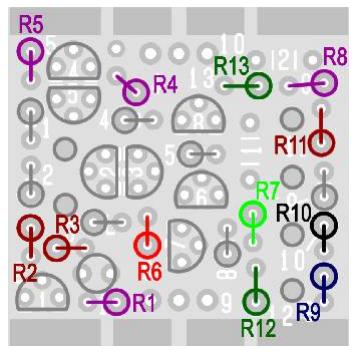
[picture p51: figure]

9. Resistors
Bend sharply one of the leads against the body the resistor for a vertical insertion.
Add R1 to R13.
Warning : It is very important to check the resistors value with a DMM because the colour code can be ambiguous. For example 1K (brown-blackblack-brown-brown) can be confused with 110R (brown-brown-black-blackbrown).

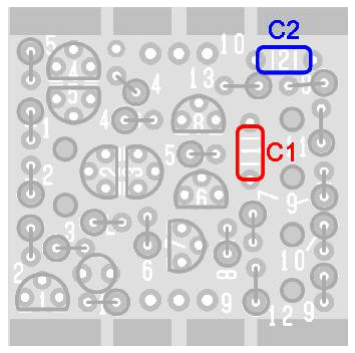
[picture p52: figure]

10. Capacitors

Add C1 and C2.

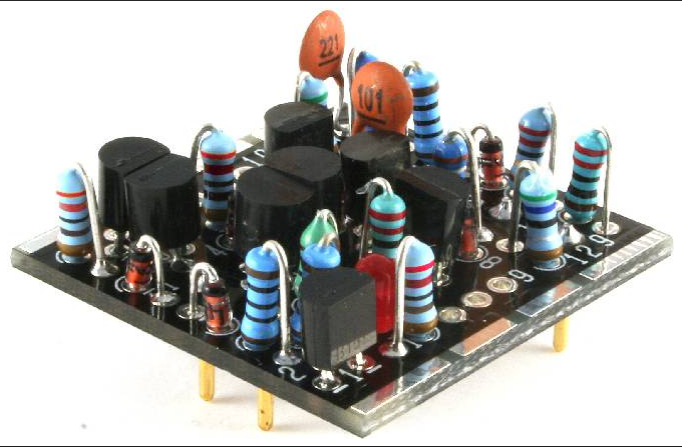
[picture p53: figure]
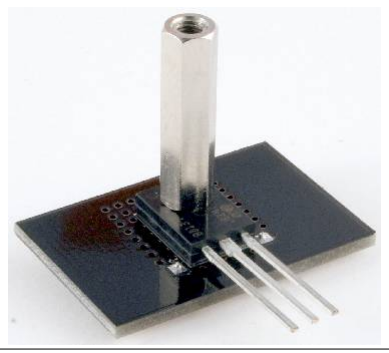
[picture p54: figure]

11. Q9 & Q10 assembly

Attach Q9 (BD139) to the heatsink PCB marked “Sound Skulptor” with a M3x12 mm screw and a M3x20 mm spacer. The transistor is placed on the side with no writing.
Tighten softly, by hand for now.

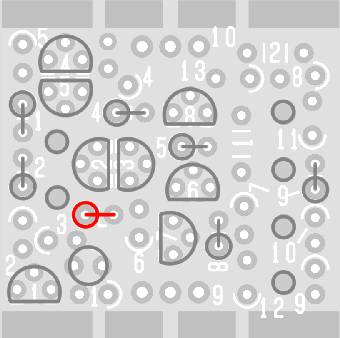
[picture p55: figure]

SK25 Assembly guide
12. Q9 & Q10 assembly
Similarly, attach Q10 (BD140) to the heatsink PCB marked “SK25” with a M3x12 mm screw and screw it into the other side of the spacer. The transistor is placed on the side with no writing.
Tighten softly, by hand for now.

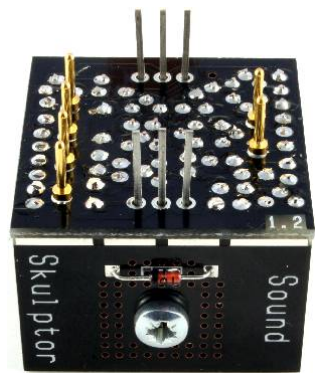
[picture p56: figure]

13. Q9 & Q10 assembly
Insert the 2 power transistor leads into the main PCB. The word “Sound” is on the input side (2 golden pins). The word “Skulptor” is on the output side (4 golden pins).
Turn upside down, press on a flat table, adjust the position, making sure that the heatsinks are parallel to the main PCB edge then solder the transistor pins. Cut the leads sharp.
Keeping the DOA pressed against the table, tighten the 2 screws with a screwdriver.
14. Q9 & Q10 assembly

Solder the 4 pads on both heatsinks. These solders improve the mechanical stiffness of the DOA and make the electrical connection of diodes D5 & D6.

15. R1

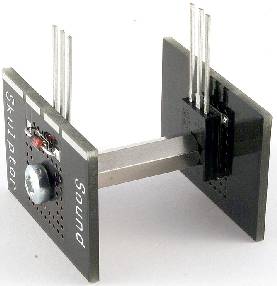
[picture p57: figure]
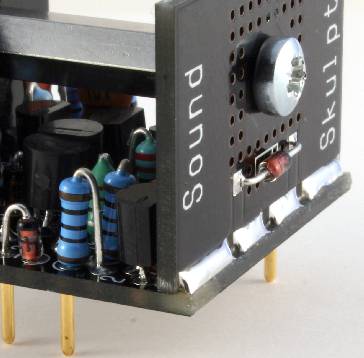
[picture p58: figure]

Pull R1 back a little in order to avoid its top touching the solder joint of D5. In several cases we have seen failures caused by such a contact in spite of the paint covering the resistor body.

16. D5 & D6 thermal contact
Press the body of D5 and D6 against the heatsink and put a drop of instant glue between the diode and the heatsink. This will ensure a permanent thermal contact between the two.
17. Congratulations!
Your SK25 is ready for test.

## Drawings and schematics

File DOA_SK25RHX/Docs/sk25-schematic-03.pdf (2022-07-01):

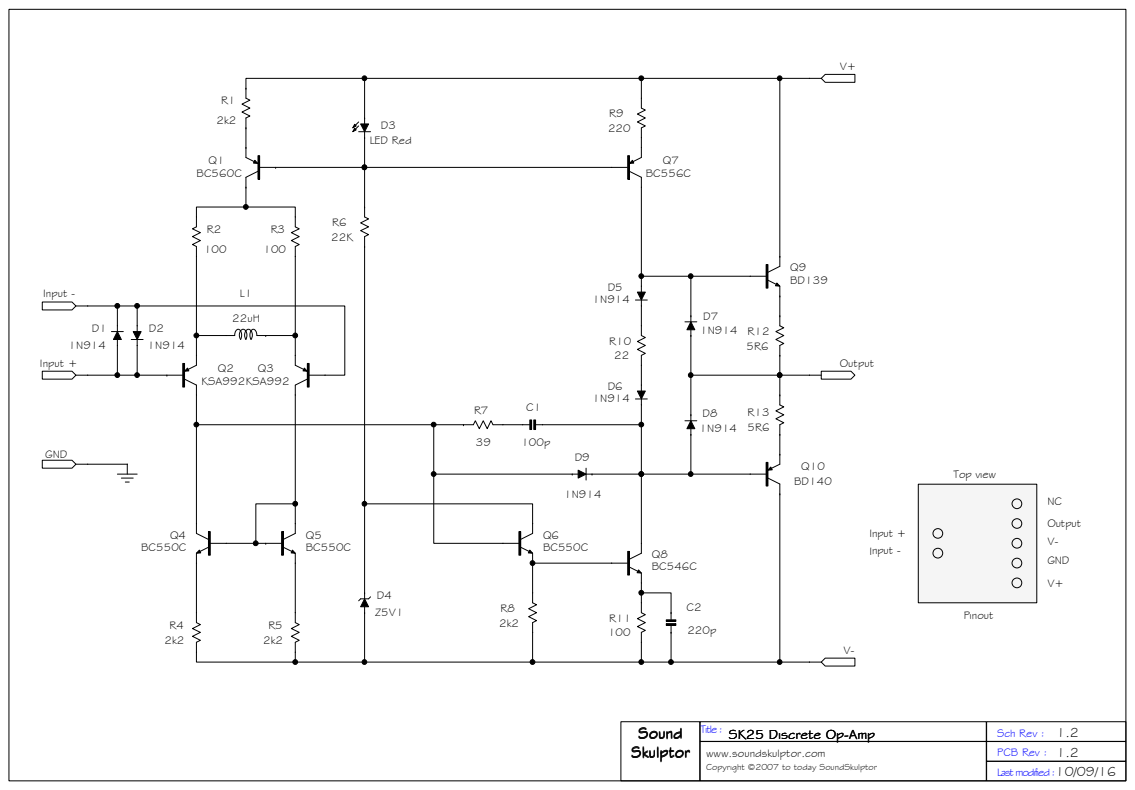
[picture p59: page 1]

SK25 Discrete Op-Amp
Copyright ©2007 to today SoundSkulptor

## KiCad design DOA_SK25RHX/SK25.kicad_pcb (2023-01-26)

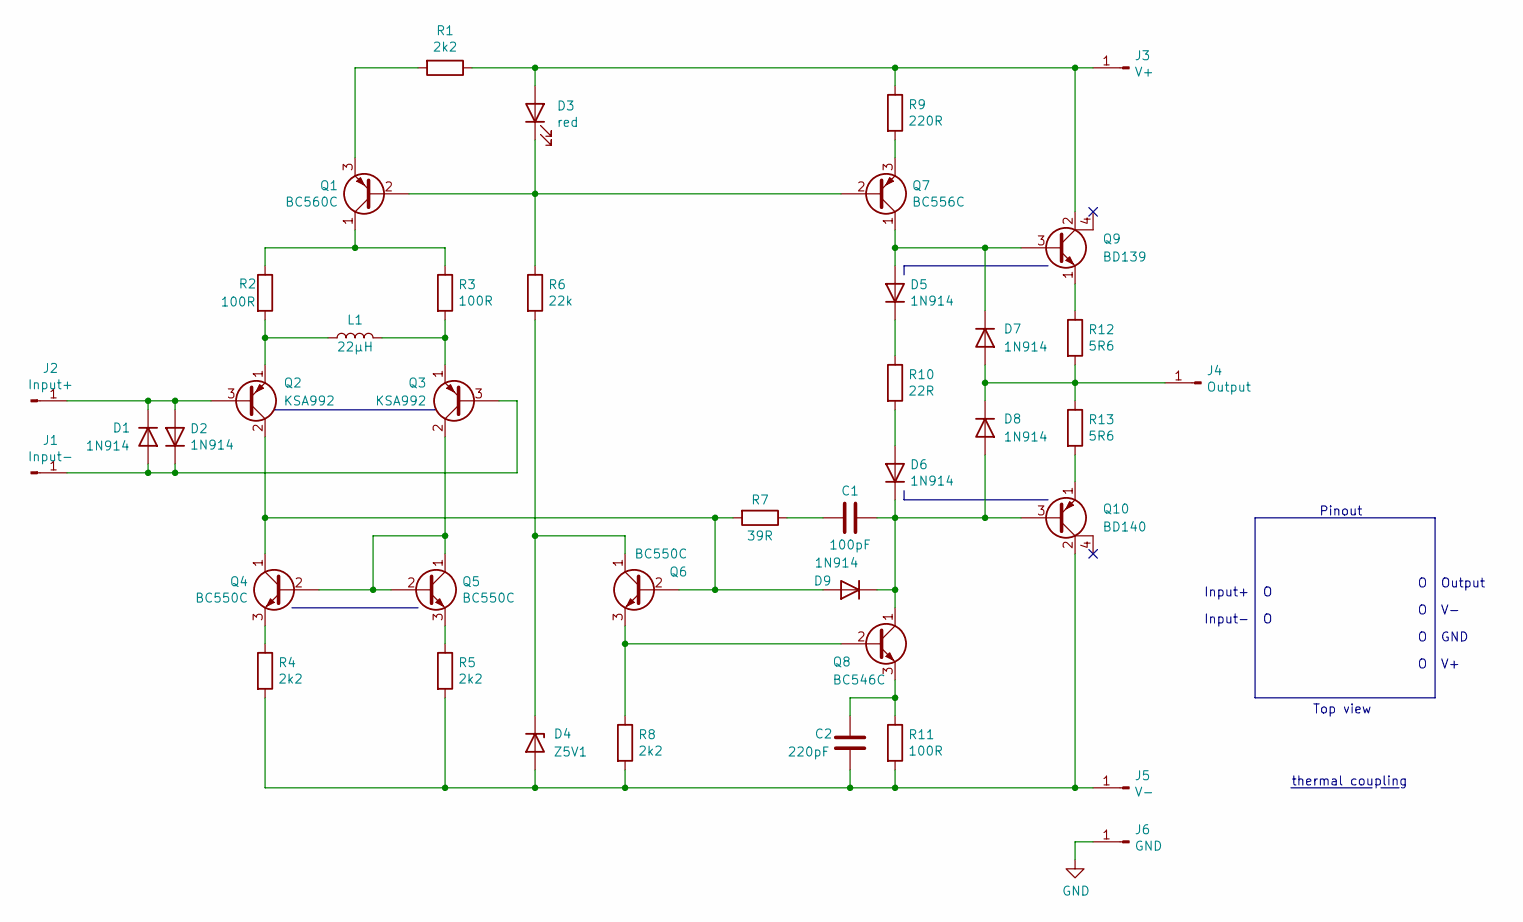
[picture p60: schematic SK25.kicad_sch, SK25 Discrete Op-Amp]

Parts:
C1: 100pF; C_Disc_D5.0mm_W2.5mm_P2.50mm
C2: 220pF; C_Disc_D5.0mm_W2.5mm_P2.50mm
D1, D2, D7, D8, D9: 1N914; D_DO-35_SOD27_P2.54mm_Vertical_KathodeUp
D3: red; LED_D3.0mm
D4: Z5V1; D_DO-35_SOD27_P2.54mm_Vertical_AnodeUp
D5, D6: 1N914; D_DO-35_SOD27_P10.16mm_Horizontal
J1: Input-; Pin_D1.1mm_L8.5mm_W2.5mm_FlatFork
J2: Input+; Pin_D1.1mm_L8.5mm_W2.5mm_FlatFork
J3: V+; Pin_D1.1mm_L8.5mm_W2.5mm_FlatFork
J4: Output; Pin_D1.1mm_L8.5mm_W2.5mm_FlatFork
J5: V-; Pin_D1.1mm_L8.5mm_W2.5mm_FlatFork
J6: GND; Pin_D1.1mm_L8.5mm_W2.5mm_FlatFork
L1: 22µH; L_Axial_L6.6mm_D2.7mm_P2.54mm_Vertical_Vishay_IM-2
Q1: BC560C; TO-92
Q2, Q3: KSA992; TO-92
Q4, Q5, Q6: BC550C; TO-92
Q7: BC556C; TO-92
Q8: BC546C; TO-92
Q9: BD139; to225_std
Q10: BD140; to225_std
R1, R4, R5, R8: 2k2; R_Axial_DIN0207_L6.3mm_D2.5mm_P2.54mm_Vertical
R2, R3, R11: 100R; R_Axial_DIN0207_L6.3mm_D2.5mm_P2.54mm_Vertical
R6: 22k; R_Axial_DIN0207_L6.3mm_D2.5mm_P2.54mm_Vertical
R7: 39R; R_Axial_DIN0207_L6.3mm_D2.5mm_P2.54mm_Vertical
R9: 220R; R_Axial_DIN0207_L6.3mm_D2.5mm_P2.54mm_Vertical
R10: 22R; R_Axial_DIN0207_L6.3mm_D2.5mm_P2.54mm_Vertical
R12, R13: 5R6; R_Axial_DIN0207_L6.3mm_D2.5mm_P2.54mm_Vertical

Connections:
GND: J6.1
unnamed: C1.1, D6.1 (K), D8.2 (A), D9.1 (K), Q8.1 (C), Q10.3 (B)
unnamed: C1.2, R7.1
unnamed: C2.1, Q8.3 (E), R11.1
unnamed: C2.2, D4.2 (A), J5.1, Q10.2 (C), R4.2, R5.2, R8.2, R11.2
unnamed: D1.1 (K), D2.2 (A), J2.1, Q2.3 (B)
unnamed: D1.2 (A), D2.1 (K), J1.1, Q3.3 (B)
unnamed: D3.1 (K), Q1.2 (B), Q7.2 (B), R6.1
unnamed: D3.2 (A), J3.1, Q9.2 (C), R1.1, R9.1
unnamed: D4.1 (K), Q6.1 (C), R6.2
unnamed: D5.1 (K), R10.1
unnamed: D5.2 (A), D7.1 (K), Q7.1 (C), Q9.3 (B)
unnamed: D6.2 (A), R10.2
unnamed: D7.2 (A), D8.1 (K), J4.1, R12.2, R13.1
unnamed: D9.2 (A), Q2.2 (C), Q4.1 (C), Q6.2 (B), R7.2
unnamed: L1.1, Q2.1 (E), R2.2
unnamed: L1.2, Q3.1 (E), R3.2
unnamed: Q1.1 (C), R2.1, R3.1
unnamed: Q1.3 (E), R1.2
unnamed: Q3.2 (C), Q4.2 (B), Q5.1 (C), Q5.2 (B)
unnamed: Q4.3 (E), R4.1
unnamed: Q5.3 (E), R5.1
unnamed: Q6.3 (E), Q8.2 (B), R8.1
unnamed: Q7.3 (E), R9.2
unnamed: Q9.1 (E), R12.1
unnamed: Q10.1 (E), R13.2

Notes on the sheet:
Top view
thermal coupling
Pinout
O V-
Input- O
Input+ O
O V+
O GND
O Output

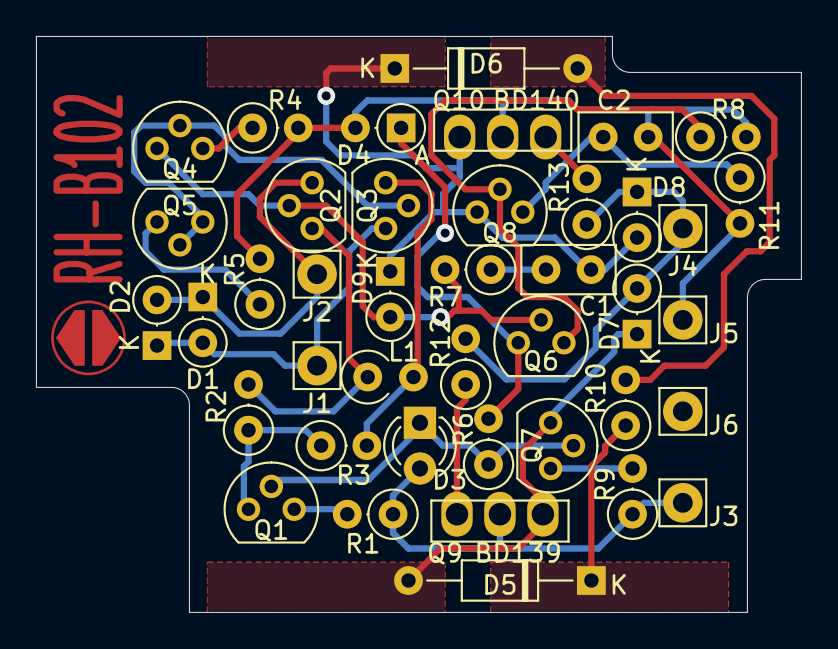
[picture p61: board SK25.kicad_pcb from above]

Board: 2 copper layers, 42.5 x 32.0 mm, 41 parts (0 on the bottom side), 25 nets.

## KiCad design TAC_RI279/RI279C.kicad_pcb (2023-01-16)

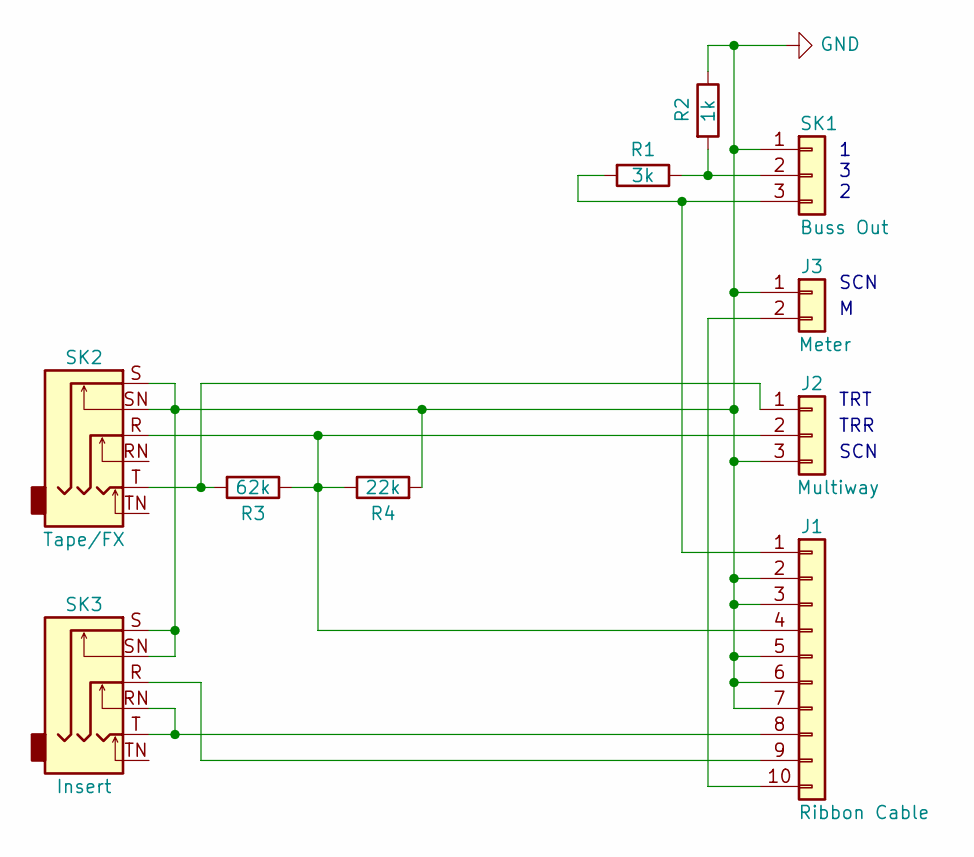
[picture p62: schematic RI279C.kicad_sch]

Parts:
J1: Ribbon Cable; Molex_KK-254_AE-6410-10A_1x10_P2.54mm_Vertical
J2: Multiway; Molex_KK-254_AE-6410-03A_1x03_P2.54mm_Vertical
J3: Meter; PinHeader_1x02_P2.54mm_Vertical
R1: 3k; R_Axial_DIN0207_L6.3mm_D2.5mm_P10.16mm_Horizontal
R2: 1k; R_Axial_DIN0207_L6.3mm_D2.5mm_P10.16mm_Horizontal
R3: 62k; R_Axial_DIN0207_L6.3mm_D2.5mm_P10.16mm_Horizontal
R4: 22k; R_Axial_DIN0207_L6.3mm_D2.5mm_P10.16mm_Horizontal
SK1: Buss Out; Molex_KK-254_AE-6410-03A_1x03_P2.54mm_Vertical
SK2: Tape/FX; CL13345
SK3: Insert; CL13345

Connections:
GND: J1.2, J1.3, J1.5, J1.6, J1.7, J2.3, J3.1, R2.1, R4.2, SK1.1, SK2.S, SK2.SN, SK3.S, SK3.SN
unnamed: J1.1, R1.2, SK1.3
unnamed: J1.4, J2.2, R3.1, R4.1, SK2.R
unnamed: J1.8, SK3.RN, SK3.T
unnamed: J1.9, SK3.R
unnamed: J1.10, J3.2
unnamed: J2.1, R3.2, SK2.T
unnamed: R1.1, R2.2, SK1.2

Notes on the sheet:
TRT
1 3 2
SCN
TRR

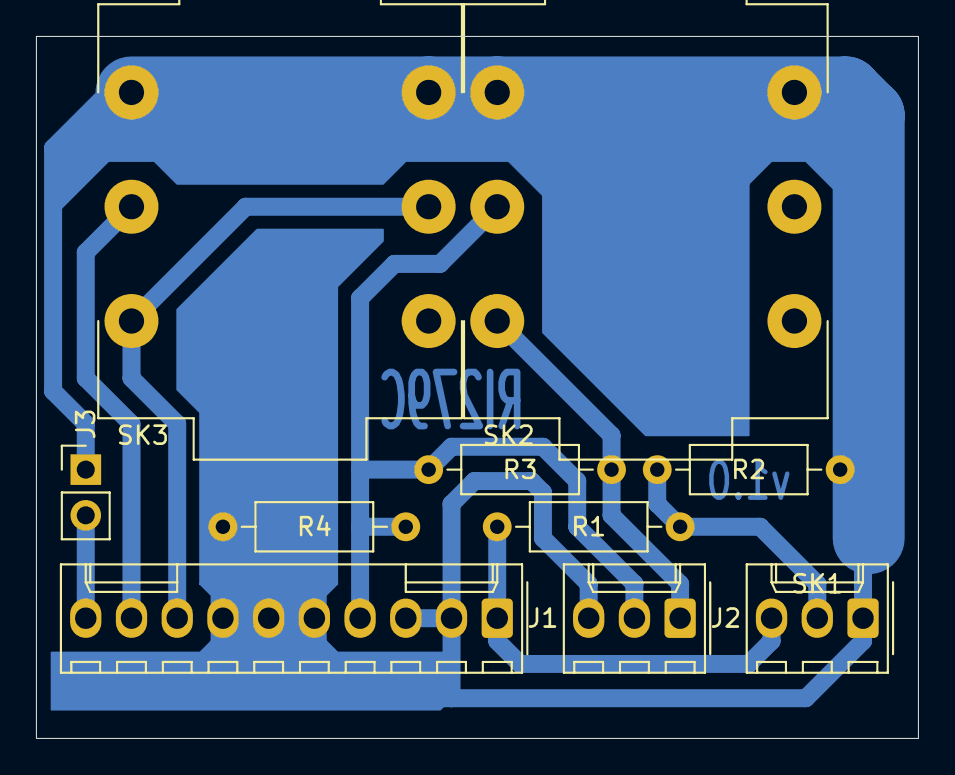
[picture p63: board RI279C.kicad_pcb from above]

Board: 2 copper layers, 49.0 x 39.0 mm, 10 parts (0 on the bottom side), 8 nets.

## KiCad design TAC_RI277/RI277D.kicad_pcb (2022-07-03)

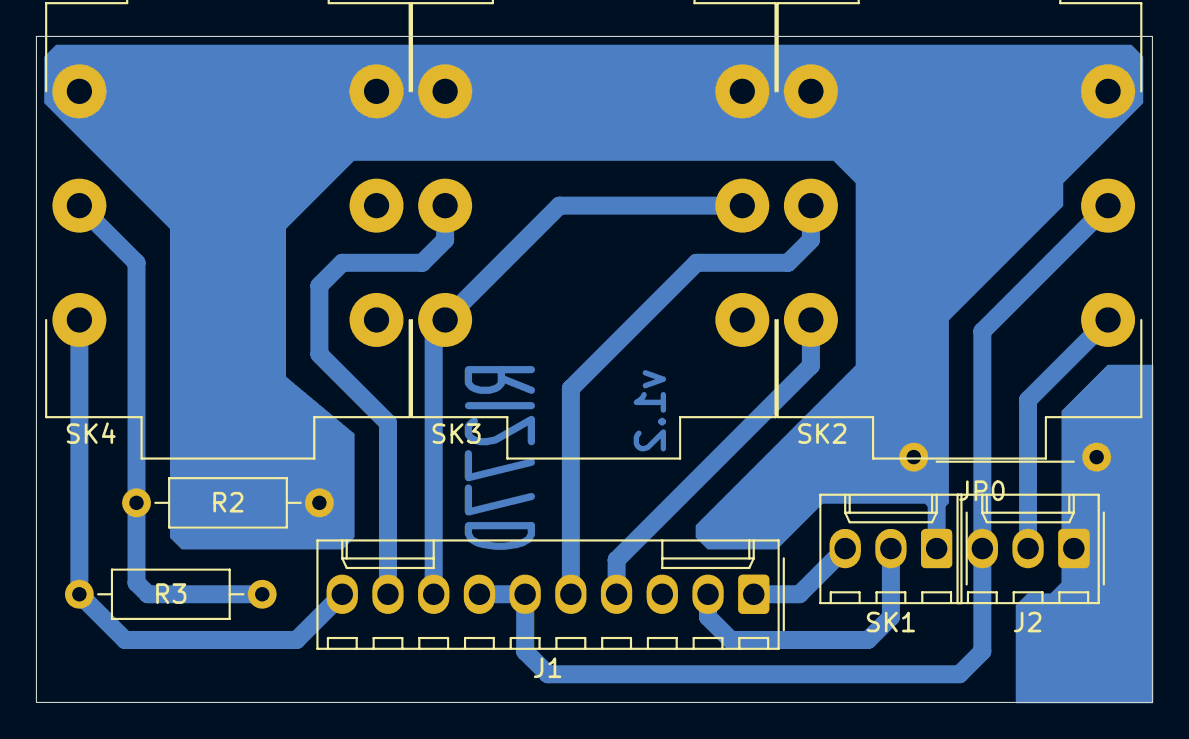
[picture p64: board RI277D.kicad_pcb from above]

Board: 2 copper layers, 62.0 x 37.0 mm, 9 parts (0 on the bottom side), 12 nets.

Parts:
J1: Ribbon Cable; Molex_KK-254_AE-6410-10A_1x10_P2.54mm_Vertical
J2: Tape Return; Molex_KK-254_AE-6410-03A_1x03_P2.54mm_Vertical
JP0: Wire_Bridge; Wire_Bridge_P10.16mm_Horizontal
R2: 1k; R_Axial_DIN0207_L6.3mm_D2.5mm_P10.16mm_Horizontal
R3: 3k; R_Axial_DIN0207_L6.3mm_D2.5mm_P10.16mm_Horizontal
SK1: MIC Input; Molex_KK-254_AE-6410-03A_1x03_P2.54mm_Vertical
SK2: Line Input; CL13345
SK3: Insert; CL13345
SK4: Direct Out; CL13345

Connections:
GND: JP0.2, R2.1, SK1.1, SK2.S, SK2.SN, SK3.S, SK3.SN, SK4.S, SK4.SN
unnamed: J1.1, SK1.3
unnamed: J1.2, SK1.2
unnamed: J1.4, SK2.T
unnamed: J1.5, SK2.R
unnamed: J1.6, J1.7, J2.3, SK2.RN
unnamed: J1.8, SK3.RN, SK3.T
unnamed: J1.9, SK3.R
unnamed: J1.10, R3.1, SK4.T
unnamed: J2.1, JP0.1
unnamed: J2.2, SK2.TN
unnamed: R2.2, R3.2, SK4.R

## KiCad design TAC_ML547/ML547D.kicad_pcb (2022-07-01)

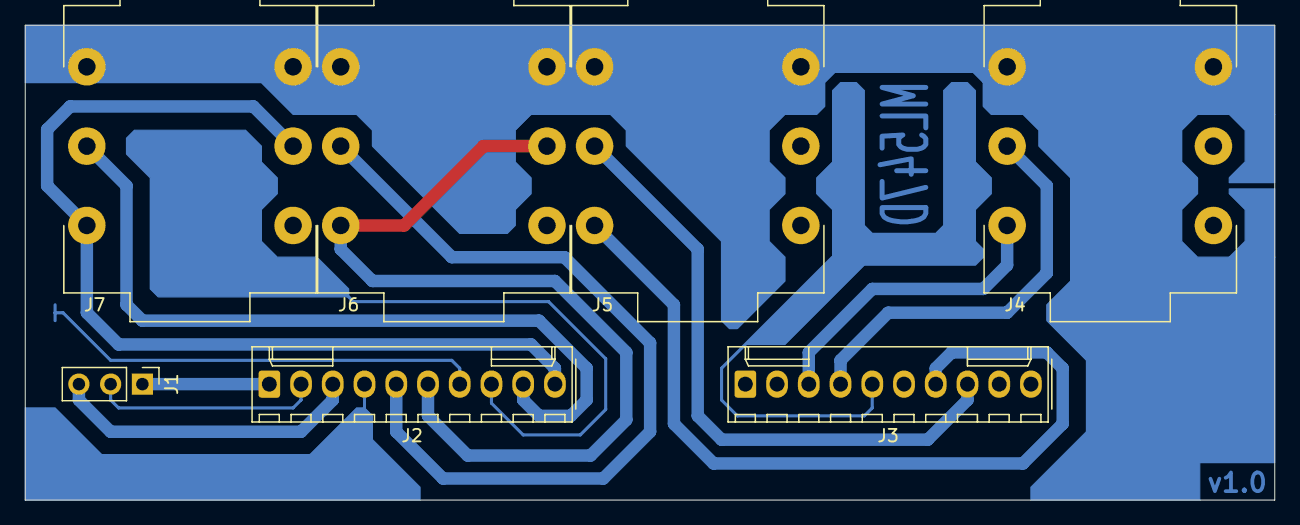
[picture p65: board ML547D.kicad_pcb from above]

Board: 2 copper layers, 100.0 x 38.0 mm, 7 parts (0 on the bottom side), 12 nets.

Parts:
J1: Direct Out; PinHeader_1x03_P2.54mm_Vertical
J2, J3: Ribbon; Molex_KK-254_AE-6410-10A_1x10_P2.54mm_Vertical_reversed
J4: Input R; CL13345
J5: Input L; CL13345
J6: Insert R; CL13345
J7: Insert L; CL13345

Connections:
unnamed: J1.1, J2.1
unnamed: J1.2, J2.2
unnamed: J1.3, J2.3
unnamed: J2.5, J6.R
unnamed: J2.6, J6.RN, J6.T
unnamed: J2.9, J7.R
unnamed: J2.10, J7.RN, J7.T
unnamed: J3.3, J4.T
unnamed: J3.4, J4.R
unnamed: J3.7, J5.T
unnamed: J3.8, J5.R
unnamed: J4.S, J4.SN, J5.S, J5.SN, J6.S, J6.SN, J7.S, J7.SN

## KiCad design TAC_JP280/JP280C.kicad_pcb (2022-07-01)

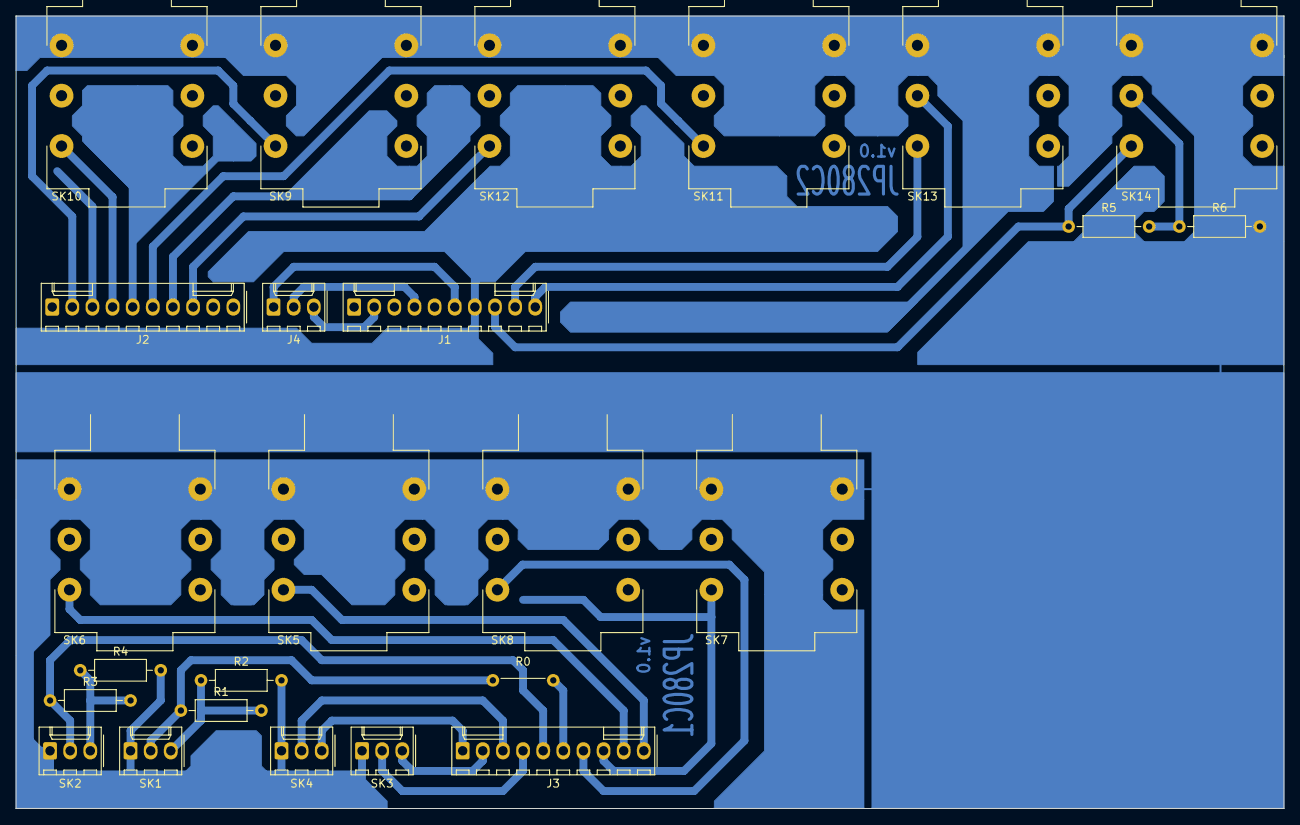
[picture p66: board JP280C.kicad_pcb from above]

Board: 2 copper layers, 160.0 x 100.0 mm, 25 parts (0 on the bottom side), 25 nets.

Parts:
J1: Ribbon Cable (A); Molex_KK-254_AE-6410-10A_1x10_P2.54mm_Vertical_reversed
J2: Ribbon Cable (B); Molex_KK-254_AE-6410-10A_1x10_P2.54mm_Vertical_reversed
J3: Ribbon Cable (C); Molex_KK-254_AE-6410-10A_1x10_P2.54mm_Vertical_reversed
J4: Meters; Molex_KK-254_AE-6410-03A_1x03_P2.54mm_Vertical_reversed
R0: 0R; Wire_Bridge_P7.62mm_Horizontal
R1, R3: 3k; R_Axial_DIN0207_L6.3mm_D2.5mm_P10.16mm_Horizontal
R2, R4: 1k; R_Axial_DIN0207_L6.3mm_D2.5mm_P10.16mm_Horizontal
R5: 10k; R_Axial_DIN0207_L6.3mm_D2.5mm_P10.16mm_Horizontal
R6: 10R; R_Axial_DIN0207_L6.3mm_D2.5mm_P10.16mm_Horizontal
SK1: Left Bus; Molex_KK-254_AE-6410-03A_1x03_P2.54mm_Vertical_reversed
SK2: Right Bus; Molex_KK-254_AE-6410-03A_1x03_P2.54mm_Vertical_reversed
SK3: Left Insert; Molex_KK-254_AE-6410-03A_1x03_P2.54mm_Vertical_reversed
SK4: Right Insert; Molex_KK-254_AE-6410-03A_1x03_P2.54mm_Vertical_reversed
SK5: Left Monitor; CL13345
SK6: Right Monitor; CL13345
SK7: Left Aux Monitor; CL13345
SK8: Right Aux Monitor; CL13345
SK9: Left Tape 2; CL13345
SK10: Right Tape 2; CL13345
SK11: Left Tape 1; CL13345
SK12: Right Tape 1; CL13345
SK13: Talkback; CL13345
SK14: OSC; CL13345

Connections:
GND: R2.2, R4.2, R6.2, SK1.1, SK2.1, SK3.1, SK4.1, SK5.S, SK5.SN, SK6.S, SK6.SN, SK7.S, SK7.SN, SK8.S, SK8.SN, SK9.S, SK9.SN, SK10.S, SK10.SN, SK11.S, SK11.SN, SK12.S, SK12.SN, SK13.S, SK13.SN, SK14.S, SK14.SN
unnamed: J1.2, J4.3
unnamed: J1.4, J4.2
unnamed: J1.6, J4.1
unnamed: J1.8, R5.1, SK14.T
unnamed: J1.9, SK13.T
unnamed: J1.10, SK13.R
unnamed: J2.2, SK9.T
unnamed: J2.4, SK10.T
unnamed: J2.6, SK11.T
unnamed: J2.8, SK12.T
unnamed: J3.1, SK4.3
unnamed: J3.2, SK3.3
unnamed: J3.3, SK4.2
unnamed: J3.4, SK3.2
unnamed: J3.5, R3.1, SK2.2
unnamed: J3.6, R0.2
unnamed: J3.7, SK8.T
unnamed: J3.8, SK7.T
unnamed: J3.9, SK6.T
unnamed: J3.10, SK5.T
unnamed: R0.1, R1.1, SK1.2
unnamed: R1.2, R2.1, SK1.3
unnamed: R3.2, R4.1, SK2.3
unnamed: R5.2, R6.1, SK14.R

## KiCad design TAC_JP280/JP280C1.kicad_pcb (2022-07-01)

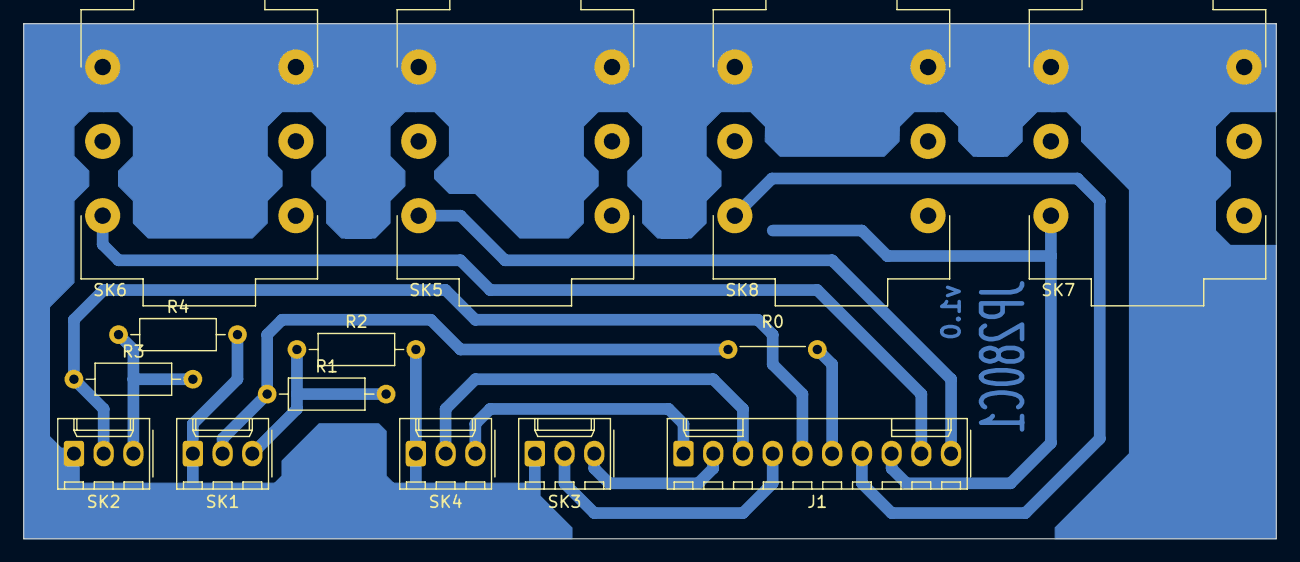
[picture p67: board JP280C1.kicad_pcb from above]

Board: 2 copper layers, 107.0 x 44.0 mm, 14 parts (0 on the bottom side), 14 nets.

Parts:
J1: Ribbon Cable (C); Molex_KK-254_AE-6410-10A_1x10_P2.54mm_Vertical_reversed
R0: 0R; Wire_Bridge_P7.62mm_Horizontal
R1, R3: 3k; R_Axial_DIN0207_L6.3mm_D2.5mm_P10.16mm_Horizontal
R2, R4: 1k; R_Axial_DIN0207_L6.3mm_D2.5mm_P10.16mm_Horizontal
SK1: Left Bus; Molex_KK-254_AE-6410-03A_1x03_P2.54mm_Vertical_reversed
SK2: Right Bus; Molex_KK-254_AE-6410-03A_1x03_P2.54mm_Vertical_reversed
SK3: Left Insert; Molex_KK-254_AE-6410-03A_1x03_P2.54mm_Vertical_reversed
SK4: Right Insert; Molex_KK-254_AE-6410-03A_1x03_P2.54mm_Vertical_reversed
SK5: Left Monitor; CL13345
SK6: Right Monitor; CL13345
SK7: Left Aux Monitor; CL13345
SK8: Right Aux Monitor; CL13345

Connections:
GND: R2.2, R4.2, SK1.1, SK2.1, SK3.1, SK4.1, SK5.S, SK5.SN, SK6.S, SK6.SN, SK7.S, SK7.SN, SK8.S, SK8.SN
unnamed: J1.1, SK4.3
unnamed: J1.2, SK3.3
unnamed: J1.3, SK4.2
unnamed: J1.4, SK3.2
unnamed: J1.5, R3.1, SK2.2
unnamed: J1.6, R0.2
unnamed: J1.7, SK8.T
unnamed: J1.8, SK7.T
unnamed: J1.9, SK6.T
unnamed: J1.10, SK5.T
unnamed: R0.1, R1.1, SK1.2
unnamed: R1.2, R2.1, SK1.3
unnamed: R3.2, R4.1, SK2.3

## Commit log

2022-07-01 Merged all TAC related repositories into this new one.
    [AML-07-046.kicad_pcb, AML-07-046.sch, AML-07-048.kicad_pcb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]
2022-07-01 input section of S1000
    [GL270D.kicad_pcb, GL270D.sch]
2022-07-02 fix in MicIn schematic, BJT section of S1000
    [AML-07-048.sch, GL270D.sch]
2022-07-02 fully drawn components of MicIn mod PCB AML-07-048
    [GL270D.sch]
2022-07-02 renamed components of AML pcb section, started drawing Eq section
    [GL270D.sch]
2022-07-03 Eq middle section
    [GL270D.sch]
2022-07-03 completed EQ section
    [GL270D.sch]
2022-07-03 included RI277 to diagram, fixed missing bridge pin 6-7 on RI277D
    [GL270D.sch, RI277D.kicad_pcb, RI277D.sch]
2022-07-03 diagram makeup, updated readme
    [GL270D.sch]
2022-07-20 completed overload and part of PFL switching section
    [GL270D.sch]
2022-07-21 completed PAN section and S1100 aux send option
    [GL270D.sch]
2022-07-21 completed switching section. Have to revise pin and resistor accociation
    [GL270D.sch]
2022-07-22 revised pin assignment DIN 8-12. Need to verify DIN 13-20
    [GL270D.sch]
2022-07-24 completed MicIn diagram
    [GL270-LineIn.sch, GL270-MicIn.sch, GL270D.kicad_pcb]
2022-07-24 renamed LineIn jumpers, image cleanup
    [AML-07-046.sch]
2022-07-29 completed MicIn and LineIn circuit diagrams and fixed errors.
    [AML-07-046.sch, GL270-LineIn.sch, GL270-MicIn.sch]
2022-07-31 DOA readme
    [GL270-LineIn.sch]
2022-08-04 completed foot print assignment for DOA SK25
    [SK25.sch]
2022-08-05 crude placement
    [SK25.sch]
2022-11-17 abandoned layout. just TAC schematics for DOA socket
    [SK25.kicad_pcb, SK25.sch]
2023-01-16 updated .gitignore for KiCad 6
2023-01-16 status before using KiCad 6.0
    [RI279C.kicad_pcb, RI279C.kicad_sch, SK25.kicad_pcb]
2023-01-16 expanded PBC borders to fit with TAC 270D mod clearance
    [SK25.kicad_pcb]
2023-01-23 complete plausible placement
    [SK25.kicad_pcb, SK25.kicad_sch]
2023-01-23 added PCB serial No
    [SK25.kicad_pcb]
2023-01-23 2/3 of routing
    [SK25.kicad_pcb]
2023-01-23 completed routing, except diose pads
    [SK25.kicad_pcb, SK25.kicad_sch]
2023-01-24 completed routing, added solder pads and solder mask clearance
    [SK25.kicad_pcb]
2023-01-25 small adjustments
    [SK25.kicad_pcb]
2023-01-25 uses copper fill zones
    [SK25.kicad_pcb]
2023-01-25 modified BJT footprints
    [SK25.kicad_pcb, SK25.kicad_sch]
2023-01-25 generated gerber files
    [SK25-B_Cu.gbr, SK25-B_Mask.gbr, SK25-Edge_Cuts.gbr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]
2023-01-26 fixed Mask position
    [SK25.kicad_pcb]
2023-01-26 created gbr files
    [SK25-B_Cu.gbr, SK25-B_Mask.gbr, SK25-Edge_Cuts.gbr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]
2023-02-25 created BOM
    [BOM.ods]
2023-12-26 created new KiCad project for DOA circuit in separate folder
    [GL270-DOA2520.kicad_pro.kicad_sch, GL270-LineIn.kicad_sch, GL270-MicIn.kicad_sch]
2023-12-30 first iteration DOA Mod circuit diagram
    [GL270-DOA2520.kicad_pro.kicad_sch]
